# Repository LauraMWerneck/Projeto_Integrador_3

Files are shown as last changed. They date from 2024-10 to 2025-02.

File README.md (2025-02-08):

# 📦 Projeto Integrador 3 - Controle Automático de Caixa d'Água

## 🔍 Visão Geral

O **Projeto Integrador 3** tem como objetivo o desenvolvimento de um sistema inteligente para o controle automatizado de uma caixa d'água. O sistema foi projetado para monitorar e gerenciar o nível de água na caixa utilizando sensores e tecnologia de comunicação sem fio (Wi-Fi). A ESP32 é a placa responsável pela coleta dos dados e pela comunicação com o backend, enquanto o aplicativo web proporciona uma interface visual para o usuário.

### Funcionalidades Principais:
- **Monitoramento de Nível de Água:** O sensor ultrassônico HC-SR04 é utilizado para medir a distância da superfície da água, estimando seu nível e volume na caixa d'água.
- **Controle de Vazão:** O sensor de vazão YF-S201 é utilizado para monitorar a quantidade de água consumida e o fluxo de água na caixa.
- **Integração com a Internet:** A ESP32 utiliza Wi-Fi para enviar os dados coletados para um backend em Python, o qual armazena e processa as informações.
- **Exibição no Aplicativo:** O aplicativo web mostra os dados de vazão e nível de água em tempo real, permitindo que o usuário monitore a caixa d'água de forma intuitiva.
- **Controle da Válvula Solenóide:** O sistema inclui uma válvula solenóide controlada por um módulo relé, que permite desligar ou ligar o fluxo de água, dependendo dos dados de nível.

## 🚀 Como Funciona

### 1. **Sensores**
   O sistema conta com dois sensores principais:
   - **Sensor de Vazão (YF-S201):** Mede a quantidade de água que passa por um tubo, enviando pulsos à ESP32. A partir desses pulsos, a ESP32 calcula a vazão de água (litros por minuto) e o volume total consumido.
   - **Sensor Ultrassônico (HC-SR04):** Mede a distância entre o sensor e a superfície da água, permitindo calcular o nível de água na caixa. Isso é feito utilizando o tempo de retorno de um sinal ultrassônico.

### 2. **Placa e Circuito**
   A ESP32 é a central de processamento do sistema. Ela recebe os dados dos sensores, processa as informações e envia esses dados para o backend via Wi-Fi. O circuito inclui:
   - **Conversor de Tensão:** Para fornecer 5V aos sensores que exigem essa tensão de alimentação.
   - **Módulo Relé:** Controla a válvula solenóide para permitir o controle do fluxo de água.

### 3. **Backend**
   O backend é implementado em **Python** e recebe os dados enviados pela ESP32 através de requisições HTTP POST. Os dados são processados e armazenados, permitindo consultas e análises do comportamento do sistema.

### 4. **Aplicativo Web**
   O aplicativo web é a interface onde os dados são exibidos para o usuário. Ele mostra informações em tempo real sobre:
   - Nível de água na caixa.
   - Vazão de água e volume consumido.
   
   O backend envia as informações em formato JSON para o frontend (aplicativo web), permitindo a atualização automática e em tempo real da interface.

## 📂 Estrutura do Repositório

```
📦 Projeto_Integrador_3  
 ┣ 📂 Etapa 1               # Documentação do que foi desenvolvido na etapa 1  
 ┣ 📂 Etapa 2               # Documentação do que foi desenvolvido na etapa 2  
 ┣ 📂 Etapa 3               # Documentação do que foi desenvolvido na etapa 3  
 ┣ 📂 Etapa 4               # Documentação do que foi desenvolvido na etapa 4  
 ┣ 📂 Projeto Final         # Pasta com os códigos e esquemáticos finais  
     ┣ 📄 main.c            # Código da ESP32  
     ┣ 📄 app.py            # Código do servidor em Python  
     ┣ 📄 index.html        # Aplicativo para visualização dos dados  
     ┣ 📂 Placa             # Esquemáticos e layout da PCB  
 ┣ 📜 README.md             # Documentação principal  
 ┣ 📜 README_1.md           # Primeiro README.md feito com o resumo do objetivo do projeto  
```

## 💻 Requisitos

Para rodar o projeto, é necessário ter os seguintes componentes e softwares:

### Hardware:
- **ESP32 (ESP-WROOM-32)** – Microcontrolador responsável pelo processamento dos dados.
- **Sensor Ultrassônico HC-SR04** – Para medição do nível de água.
- **Sensor de Vazão YF-S201** – Para medir o fluxo de água.
- **Válvula Solenóide e Módulo Relé** – Para controlar o fluxo de água.
- **Conversor de Tensão** – Para alimentar os sensores.

### Software:
- **Python 3.x** – Para rodar o backend do servidor.
- **Bibliotecas ESP32** – Para programar a ESP32.
- **HTML/CSS/JavaScript** – Para o desenvolvimento da interface do aplicativo web.

## ⚙️ Como Rodar

### 1. **Configuração da ESP32:**
   - Baixe o código da ESP32 (main.c) e configure a placa utilizando o ESP-IDF do Visual Studio Code.
   - Conecte os sensores de vazão e ultrassônicos aos pinos apropriados na ESP32.
   - Configure a conexão Wi-Fi com as credenciais da sua rede.

### 2. **Configuração do Backend:**
   - Clone o repositório e instale as dependências necessárias para rodar o servidor em Python.
   - Execute o código Python (`app.py`) para iniciar o backend.
   - O backend estará escutando as requisições HTTP POST enviadas pela ESP32.

### 3. **Interface Web:**
   - Abra o arquivo `index.html` em um navegador para acessar a interface do aplicativo.
   - O frontend vai se conectar automaticamente ao backend para visualizar os dados em tempo real.

### 4. **Testes e Monitoramento:**
   - Teste o sistema monitorando os dados de vazão e nível de água, além de verificar o controle da válvula solenóide através da interface web.

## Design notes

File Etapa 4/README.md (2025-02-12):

# Resumo do que foi desenvolvido na etapa

## Comunicação WiFi da ESP (Sensores mandando dados para o aplicativo)

A primeira parte desenvolvida nessa etapa foi a implementação da comunicação entre a ESP32 e o backend do aplicativo, permitindo que a ESP enviasse os dados dos sensores de forma eficiente. Utilizando a conectividade Wi-Fi da ESP32, foi integrado o envio de dados coletados dos sensores (como vazão de água, volume total acumulado e distância medida por ultrassônico) para o backend, que é implementado em Python. O código de coleta de dados, previamente funcional, foi adaptado para incluir o envio dessas informações em formato JSON por meio de requisições HTTP POST ao servidor. Isso garante que os dados sejam transmitidos em tempo real, utilizando uma comunicação robusta e compatível com o backend.

Para testar essa funcionalidade, carregamos o novo código na ESP32 e executamos o código do backend em Python. Com as credenciais de Wi-Fi configuradas corretamente, os dados enviados pela ESP começaram a aparecer no terminal onde o backend estava rodando, conforme ilustrado na Figura 1. Além disso, para validar a estabilidade da comunicação Wi-Fi, conectamos a ESP a uma fonte de alimentação independente e observamos que ela continuou transmitindo os dados de forma consistente para o backend. Esse teste confirmou que a comunicação Wi-Fi estava funcionando corretamente e de maneira estável.

Figura 1: Backend recebendo dados no terminal via WiFi.
teste_wifi
Fonte: Autoria Própria.

Os códigos comentados utilizados para esse teste estão disponíveis [aqui](https://github.com/LauraMWerneck/Projeto_Integrador_3/tree/main/Etapa%204/Teste%20WiFi).

## Criação da Placa
Na análise do esquemático criado na Etapa 3, identificamos soluções mais simples e eficazes para atender aos requisitos do projeto. Adotamos uma fonte de 12V via conector P4, que alimenta tanto a solenóide através do relé quanto um conversor 7805 para fornecer 5V à ESP32 e aos sensores. Também substituímos o módulo de relé por um relé simples, tornando o circuito mais compacto e reduzindo custos sem comprometer a eficiência.

Durante os testes, identificamos instabilidades devido à ausência de capacitores de desacoplamento no 7805, especialmente ao acionar o relé. A adição desses capacitores estabilizou a alimentação. Além disso, o sensor de fluxo apresentou falhas com os 5,05V fornecidos pelo 7805, sendo corrigido com um diodo em série, reduzindo a tensão e melhorando seu desempenho.

Após os ajustes, o circuito revisado mostrou-se mais estável e eficiente. As melhorias foram implementadas diretamente no esquemático, conforme mostra a Figura 2 e no layout da PCB, como mostra a Figura 3, garantindo uma versão pronta para fabricação e montagem.

Figura 2: Novo esquemático do circuito.



Fonte: Autoria Própria.

Figura 3: Novo layout da placa.



Fonte: Autoria Própria.

Após a fabricação da placa, e a instalação dela no sistema físico de teste ela ficou como mostra a Figura 4.

Figura 4: Placa integrando todos os componentes.

Imagem do WhatsApp de 2025-02-10 à(s) 20 37 38_9340aac4

Fonte: Autoria Própria.

Para mais detalhes das modificações da placa, e para acessar o projeto do Kicad clique [aqui](https://github.com/LauraMWerneck/Projeto_Integrador_3/tree/main/Projeto%20Final/Placa)

## Sistema Físico de Teste
Como visto na Etapa 3, criamos um sistema físico de teste e, nesta última etapa, aprimoramos sua estrutura para acomodar a ESP e a nova placa de forma mais segura e com aparência de um produto final. Para isso, desenvolvemos um suporte impresso em 3D, fixado acima do balde principal, garantindo a estabilidade da ESP e dos sensores durante os testes. O projeto da impressão 3D está ilustrado na Figura 5.

Figura 5: Suporte 3D desenvolvido.

modelo_3D

Fonte: Autoria Própria.

Após a impressão da peça, e da integração da placa com os sensores o sistema físico de teste ficou como mostra a Figura 4, a Figura 6 e a Figura 7.

Figura 6: Suporte aberto no sistema físico de teste.

Imagem do WhatsApp de 2025-02-10 à(s) 21 38 06_a600479e

Fonte: Autoria Própria.

Figura 7: Suporte fechado no sistema físico de teste.

Imagem do WhatsApp de 2025-02-10 à(s) 21 37 33_552d8dbc

Fonte: Autoria Própria.

Para acessar o modelo 3D criado clique [aqui](https://www.tinkercad.com/things/hdSAljJmEcl-pi3?sharecode=l4aGRgi_aN5EzP9HnUlWbnjf8VeXGf09ikW7ILrOMxc)

## Criação das Funcionalidades do Aplicativo

O código do aplicativo app.py utiliza Flask para monitoramento do consumo de água e controle da caixa d'água. Ele recebe e processa dados de sensores, gerencia configurações e fornece informações para um painel em tempo real.

### **Principais Funcionalidades**
- **Recepção de Dados (/ESP_data):** Captura informações dos sensores, como distância, volume e vazão de água. Processa esses dados para calcular o consumo, estimar o tempo de disponibilidade da água e gerar alertas em caso de anomalias, como falta de água.
- **Cadastro de Configurações (/save_data):** Permite que o usuário registre informações como consumo do hidrômetro, custo da água e volume da caixa d’água. Os dados são armazenados para cálculos e análises futuras.
- **Logs em Tempo Real (/logs_stream):** Utiliza Server-Sent Events (SSE) para enviar atualizações contínuas ao frontend, garantindo que os dados exibidos na interface estejam sempre atualizados sem necessidade de recarregamento da página.
- **Leitura de Dados:** O sistema acessa um arquivo local para recuperar configurações e dados históricos do consumo, garantindo continuidade e rastreabilidade das informações.
- **Cálculos:**
  - **Custo por Litro de Água:** Obtido dividindo o custo total da água pelo consumo registrado.
  - **Consumo por Minuto e Hora:** O sistema armazena e exibe a taxa de consumo ao longo do tempo, permitindo uma análise detalhada do uso da água.
  - **Estimativa de Disponibilidade:** Com base na taxa de consumo e no volume atual da caixa d’água, o sistema prevê o tempo restante antes do esgotamento.
  - **Detecção de Falta de Água:** Se os sensores indicam um nível muito baixo, um alerta é gerado para notificar o usuário sobre o problema.

### **Interface Web**
A página HTML fornece uma interface interativa para o monitoramento e controle do consumo de água. Ela inclui:

- **Painel de Monitoramento:**
  - Exibe informações em tempo real sobre consumo, custo e volume disponível.
  - Apresenta alertas visuais sobre possíveis problemas, como baixo nível de água.
- **Gráficos Dinâmicos:**
  - Usa Chart.js para criar gráficos interativos que mostram o consumo de água ao longo do tempo.
  - O usuário pode alternar entre diferentes visualizações, como consumo por minuto, por hora ou por dia.
- **Logs de Alertas:**
  - Registra e exibe eventos importantes, como discrepâncias no consumo e notificações de falta de água.
  - Permite que o usuário acompanhe o histórico de alertas.
- **Formulário de Configuração:**
  - O usuário pode inserir e atualizar dados essenciais, como volume da caixa d’água, custo da água e consumo registrado.
  - Inclui campos para definir metas de consumo e monitorar os custos mensais.
- **Botões Interativos:**
  - Permitem alternar entre diferentes gráficos e logs.
  - Incluem funcionalidades para salvar e enviar novas configurações ao backend.

Os códigos do app.py e da página html podem ser acessados e ter sua documentação detalhada [aquqi](https://github.com/LauraMWerneck/Projeto_Integrador_3/tree/main/Projeto%20Final).

## Teste Final
Com todas as funcionalidades do aplicativo concluídas, a placa integrando os componentes e o sistema físico finalizado, além da comunicação Wi-Fi operando corretamente, chegou o momento de testar o projeto como um todo. O objetivo era garantir seu funcionamento conforme o esperado e verificar se os sensores estavam coletando os dados corretamente.

Assim, ligamos todo o sistema, conectamos os componentes necessários e, visualmente, o projeto com o sistema físico de teste ficou conforme ilustrado na Figura 8.

Figura 8: Protótipo Final.

Imagem do WhatsApp de 2025-02-10 à(s) 20 39 52_edbd3d94

Fonte: Autoria Própria.

Em seguida, inicializamos o sistema e abrimos o aplicativo. Nele, realizamos as configurações necessárias, e logo começou a receber os dados dos sensores e exibi-los para os usuários, conforme ilustrado na Figura 9.

Figura 9: Interface do Aplicativo.

Imagem do WhatsApp de 2025-02-11 à(s) 21 16 24_23b2c37d

Fonte: Autoria Própria.

# Conclusão do Projeto
O desenvolvimento deste projeto permitiu a integração eficiente de sensores de vazão e volume de água com a ESP32, garantindo a captação e transmissão de dados em tempo real para um aplicativo via Wi-Fi. A implementação bem-sucedida da comunicação entre os sensores e o backend assegurou um monitoramento contínuo e preciso dos níveis de água, proporcionando uma solução funcional para o controle de reservatórios.  

Ao longo das etapas, enfrentamos desafios técnicos como a escolha e calibração dos sensores, a revisão do circuito eletrônico e a estabilidade da comunicação Wi-Fi. A necessidade de ajustes no esquemático da placa e a reorganização dos componentes foram superadas, resultando em uma estrutura mais otimizada e confiável. Além disso, a implementação do backend em Python garantiu uma integração eficiente entre os sensores e o aplicativo, permitindo que os dados fossem processados e exibidos de maneira intuitiva para o usuário.  

O teste final comprovou o funcionamento adequado do sistema, validando a precisão das medições e a estabilidade da transmissão de dados. A interface do aplicativo foi aprimorada para facilitar o uso e a interpretação das informações coletadas. Apesar dos desafios enfrentados, o projeto demonstrou sua viabilidade e abriu caminhos para melhorias, como a otimização da precisão do sensor ultrassônico e a integração de novos recursos, como o controle automatizado da válvula solenoide.  

Com isso, o projeto atinge seu objetivo de oferecer uma solução acessível e eficiente para o monitoramento e controle de água em reservatórios, trazendo benefícios tanto para economia de recursos quanto para a gestão inteligente do consumo hídrico.

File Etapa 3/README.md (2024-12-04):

# Resumo do que foi desenvolvido na Etapa 3

## Testes Individuais dos Sensores

### Sensor de Vazão
Para testar o sensor de vazão (YF-S201), foi desenvolvido um código que recebe os pulsos gerados pelo sensor durante a passagem de água e calcula a vazão com base nesses pulsos e no fator de calibração específico do sensor. O código exibe os resultados do teste, mostrando a vazão em litros por minuto e litros por hora, além de informar o volume total de água que passou pelo sensor desde que o sistema foi iniciado. 

A explicação mais detalhada sobre o teste, juntamente com o código utilizado e sua documentação, está disponível neste [link](https://github.com/LauraMWerneck/Projeto_Integrador_3/blob/main/Etapa%203/Sensor%20de%20Vaz%C3%A3o/README.md).

### Sensor de Volume
Para validar o funcionamento do sensor ultrassônico HC-SR04 no cálculo de volumes de água, foi realizado um teste que avaliou sua precisão em medições de distância. O sistema integrou dados de distância e vazão, ajustando dinamicamente o ponto de referência do sensor conforme o nível de água. Durante o experimento, foram adicionados volumes graduais de água em um balde e comparados os níveis medidos pelo sensor com medições feitas por trena. Os resultados demonstraram que a relação entre o nível e o volume é não linear devido ao formato do recipiente, mas indicaram a viabilidade de criar funções para estimar automaticamente o volume em diferentes recipientes.

O código utilizado no teste, que configura o sensor, realiza medições contínuas e permite ajustes por comandos seriais, está documentado e disponível neste [link](https://github.com/LauraMWerneck/Projeto_Integrador_3/blob/main/Etapa%203/Sensor%20de%20Volume/README.md). O teste concluiu que o sensor ultrassônico é aplicável para medições dinâmicas de volume no projeto, com precisão suficiente para as demandas propostas.

## Integração de Todos os Sensores

Para integrar todos os sensores, começamos planejando o circuito com todos os componentes. Durante essa etapa e durante os testes individuais dos sensores, percebemos a necessidade de adicionar novos elementos, como o conversor de tensão e o módulo relé. Assim, foi elaborado o circuito que inclui não apenas os sensores, mas também a válvula solenóide. A Figura 1 a seguir apresenta o circuito resultante que montamos.

Figura 1: Circuito com os componentes e sensores.
circuito_componentes
Fonte: Autoria Própria.

Este circuito é composto pelo módulo ESP32 (ESP Wroom 32), o sensor de vazão YF-S201, o sensor ultrassônico HC-SR04, uma válvula solenóide, um módulo relé de 5V e um conversor de tensão. A ESP32 alimenta o conversor de tensão, que, por sua vez, fornece energia para os sensores e o módulo relé. A ESP32 é conectada aos sensores por meio de suas saídas de dados. A válvula solenóide e o módulo relé são alimentados por uma fonte de 12V.

É importante ressaltar que para esse primeiro teste de integração de todos os sensores, foi montado um circuito com os componentes principais, sem a inclusão do módulo relé e da válvula solenóide.

### Testes Experimentais

Para a realização dos testes com a integração de todos os sensores, foi desenvolvido um código que combinou tanto a parte do sensor de vazão quanto a do sensor de volume. Entretanto, para os testes dos sensores, foi montado um circuito com os componentes principais, mas sem a inclusão do módulo relé e da válvula solenóide.. A documentação detalhada desse código pode ser acessada através deste [link](https://github.com/LauraMWerneck/Projeto_Integrador_3/blob/main/Etapa%203/Integra%C3%A7%C3%A3o%20dos%20Sensores/README.md), e o código completo está disponível neste outro [link](https://github.com/LauraMWerneck/Projeto_Integrador_3/blob/main/Etapa%203/Integra%C3%A7%C3%A3o%20dos%20Sensores/integracao_sensores.c).

Inicialmente, o circuito e os sensores foram testados sem água, apenas com o circuito montado. No caso do sensor de volume (ultrassônico), foi realizada a medição de distância ao afastar e aproximar a mão da entrada do sensor. Para testar o sensor de vazão, foi simulado o fluxo de água ao assoprar na entrada do sensor, fazendo com que a hélice girasse como se a água estivesse passando. Um vídeo desse teste inicial pode ser visualizado abaixo.

Vídeo 1: Primeiro teste com todos os sensores.

https://github.com/user-attachments/assets/cf840823-a034-4f19-821a-5b99ec565559

Fonte: Autoria Própria.

Foi realizado um segundo teste, desta vez utilizando água. Esse teste considerou o sistema físico que montamos, composto por dois baldes, uma bomba de água e tubulações. O funcionamento do sistema é o seguinte: o balde inferior, cheio de água, alimenta a bomba, que utiliza uma mangueira conectada ao sensor para bombear a água. Após passar pelo sensor, a água é conduzida por outra mangueira e despejada no balde superior. O sensor de volume (ultrassônico) foi posicionado acima do balde superior para medir a distância entre o sensor e a superfície da água.

As Figura 2, 3 e 4 mostram como ficou o sistema físico montado, os resultados obtidos no teste forma os mesmos do testado sem água, somente o sensor ultrassônico que notamos que ele não calcula tão corretamente a distância da superfície da água, mas isso já está sendo estudado e resolvido.

Figura 2: Sistema físico de teste.

sistema_fisico_3

Fonte: Autoria Própria.

Figura 3: Sistema físico visto por cima.

sistema_fisico_2

Fonte: Autoria Própria.

Figura 4: Sistema físico vista lateral.

sistema_fisico_1

Fonte: Autoria Própria.

### Criação do Circuito Completo

Para a criação do circuito completo, consideramos os principais componentes do nosso projeto: os sensores de vazão (YF-S201) e ultrassônico (HC-SR04), além da ESP32 (ESP Wroom 32). Durante o processo, identificamos a necessidade de utilizar um conversor de tensão de 3,3V para 5V, pois o sensor ultrassônico só funcionava corretamente com essa alimentação. Além disso, o sensor de vazão apresentou melhor calibragem e resultados mais precisos quando operando com 5V. Para atender a essa demanda, utilizamos um Módulo Regulador de Tensão Ajustável MT3608 Step Up - 2,5V a 28V, aproveitando um material que já tinhamos disponível e garantindo que fosse adequado às nossas necessidades.

Adicionalmente, pensando na próxima etapa do projeto, incluímos ao circuito uma válvula solenoide. Essa válvula será responsável por controlar o fluxo de água, permitindo ou bloqueando sua passagem conforme necessário para regular o volume no reservatório. Para gerenciar a válvula, percebemos a necessidade de incluir um módulo relé, o qual também já possuíamos. A utilização desse componente irá nos permitir integrar facilmente o controle da válvula ao circuito, otimizando os recursos disponíveis.

Dessa forma, o circuito foi montado ficou como mostrado na Figura 1 e o esquemático desse circuito como mostra a Figura 2.

Figura 5: Esquemático do projeto.

esquematico

Fonte: Autoria própria.

Neste esquemático, utilizamos bibliotecas prontas para o módulo ESP32 e para o sensor ultrassônico. Entretanto, foi necessário criar os símbolos representativos para os demais componentes do circuito. Assim, desenvolvemos símbolos personalizados para representar os componentes adicionais. 

Para a elaboração da placa com os footprints, foi necessário modificar o esquemático original, uma vez que alguns componentes já possuíam conexões pré-estabelecidas ou não estariam conectados diretamente à placa. Como resultado, o esquemático final da placa ficou conforme ilustrado na Figura 3.

Figura 6: Esquemático da placa.

esquematico2

Fonte: Autoria Própria.

Para os *footprints*, utilizamos modelos já existentes para alguns itens, como o sensor de vazão (YF-S201). Em outros casos, foi necessário criar nossos próprios *footprints*, como para o regulador de tensão. O resultado final do circuito da placa que será fabricada, é apresentado na Figura 4.

Figura 7: *Layout* da PCB.

circuito_placa

Fonte: Autoria Própria.

## Desenvolvimento do Aplicativo

No aplicativo, a comunicação entre o backend e o frontend foi implementada por meio de uma API, permitindo que o usuário insira os valores necessários, que são salvos e utilizados para cálculos no backend. A próxima etapa do desenvolvimento incluirá a integração para o recebimento dos dados provenientes do microcontrolador, a transmissão dos resultados do backend para o frontend e a criação de uma interface amigável para o usuário.

Confira mais detalhes no repositório: [Projeto Integrador 3 - Aplicativo](https://github.com/LauraMWerneck/Projeto_Integrador_3/tree/main/Etapa%203/Aplicativo)

## Identificação dos Problemas

Durante o desenvolvimento do projeto diversos desafios foram enfrentados e documentados para que pudessem ser adequadamente analisados e resolvidos. Esses problemas estão relacionados tanto ao hardware quanto à implementação e integração dos componentes eletrônicos. A seguir, são detalhados os problemas identificados até o momento:

#### 1. Utilização de Pinos de Strapping na ESP32 WROOM  
Durante a montagem inicial do circuito, foram utilizados os pinos 2 e 5 da ESP32 WROOM, que são pinos críticos para o processo de "strapping". Isso gerou dificuldades ao tentar gravar o código na ESP32, já que o pino 2 é diretamente relacionado ao processo de boot. Como solução temporária, foi adotada a prática de pressionar manualmente o botão de boot durante o envio do código para a placa. No entanto, essa abordagem é pouco prática e pode gerar problemas futuros caso a necessidade de regravação do código seja frequente ou automatizada. Esse problema foi identificado e os pinos serão remanejados para evitar conflitos com as funções de strapping.

#### 2. Má utilização do Visual Studio Code
Durante o desenvolvimento do projeto, enfrentamos dificuldades ao abrir o monitor serial no Visual Studio Code, usado para programar e gravar o código na ESP32. O problema ocorreu devido a erros na organização dos arquivos do projeto e na configuração do sistema de build baseado em CMake. Criamos arquivos de maneira incorreta dentro do projeto, e o arquivo `CMakeLists.txt` não foi ajustado para identificar corretamente o arquivo principal com a função `main`. Isso gerou inconsistências durante a compilação, fazendo com que o código fosse gravado de forma incorreta na ESP32 e impedindo que o monitor serial exibisse as mensagens de saída esperadas. Para resolver, reorganizamos os arquivos respeitando a estrutura padrão do ESP-IDF. Após essa mudança, o sistema passou a compilar corretamente, e o monitor serial voltou a funcionar.

#### 3. Baixa Precisão do Sensor Ultrassônico  
O sensor ultrassônico instalado para medir o volume de água na caixa apresentou limitações de precisão nas leituras. Isso pode comprometer a confiabilidade do sistema de controle, especialmente em situações que demandam maior exatidão nos dados. Já está em andamento a investigação de possíveis melhorias no uso do sensor, como ajustes na sua posição ou alterações no código de processamento dos dados, além da análise de alternativas de sensores que possam substituir o atual.

#### 4. Integração do Sistema e Comunicação com o Aplicativo  
Embora ainda não tenha gerado problemas práticos, a integração dos dados coletados pelos sensores e sua transmissão para o aplicativo via HTML podem ser pontos de atenção. A confiabilidade na comunicação entre a ESP32 e o aplicativo será essencial para o funcionamento do sistema, especialmente em termos de velocidade e consistência na transmissão dos dados.

#### 5. Organização dos Sensores e da Placa de Controle
Outro ponto inportante para termos atenção para a próxima etapa está relacionado à organização física dos sensores, da válvula solenóide e da placa de controle. Como o projeto inclui uma placa principal com os componentes eletrônicos essenciais e conexões externas para os sensores e a válvula, é necessário planejar cuidadosamente a disposição dos cabos, a localização da placa e as medidas de proteção física para garantir a funcionalidade e a durabilidade do sistema.

Esse desafio envolve evitar o emaranhamento dos fios, que pode dificultar a manutenção e gerar interferências elétricas entre os componentes, além de pensar em uma forma de fixar a placa em um local seguro. Também é necessário garantir que a placa e as conexões estejam protegidas contra umidade, respingos de água e outras condições ambientais adversas, utilizando uma caixa ou invólucro adequado. Este problema ainda está em análise para definir a melhor solução, considerando tanto a praticidade quanto os custos envolvidos na implementação de uma organização eficiente e segura.

## Estudo da Viabilidade de Monitorar Vazamentos
O estudo de viabilidade para implementar o monitoramento de vazamentos no projeto de controle da caixa d’água concluiu que a funcionalidade não é viável devido a limitações técnicas e financeiras. O sensor de vazão existente não permite detectar vazamentos na tubulação, e a instalação de sensores adicionais aumentaria os custos e a complexidade. Métodos alternativos, como o uso de dados comparativos com o sensor ultrassônico, são imprecisos e sujeitos a falsos alarmes. Além disso, o ambiente operacional, com baixa pressão e tubulações conectadas em diferentes pontos, dificulta a confiabilidade do sistema.

Dado o alto custo de sensores especializados e a manutenção necessária para evitar falhas, optou-se por não incluir essa funcionalidade no projeto. O foco será para melhorar o controle de enchimento da caixa e a apresentação dos dados no aplicativo, mantendo a solução acessível, eficiente e funcional.

Mais detalhes do que foi levantado nessa pesquisa podem ser acessados nesse [link](https://github.com/LauraMWerneck/Projeto_Integrador_3/tree/main/Etapa%203/Estudo%20da%20Viabilidade%20de%20Monitorar%20Vazamentos)

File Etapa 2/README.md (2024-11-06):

# Resumo do que foi desenvolvido na Etapa 2

## Determinação das Fórmulas do Aplicativo

### Dados Retornados pelo Microcontrolador
O microcontrolador envia dados para o backend, usados para calcular o custo da água na região, com base nas informações da conta de água inseridas pelo usuário.

### Cálculos no Aplicativo

1. **Consumo em Reais**: Calculado considerando a hora e data.
2. **Água Disponível na Caixa d’Água**: Cálculo baseado na quantidade de água.
3. **Consumo Real**: Diferença entre o valor calculado e o hidrômetro.
4. **Tempo de Água Disponível**: Calculado com base no consumo dos últimos 3 dias.
5. **Expectativa de Consumo**: Estimativa para o próximo mês, após o primeiro mês de uso.
6. **Gasto no Próximo Mês**: Usuário define o limite, disponível após o primeiro mês.

### Funcionalidades Sem Fórmulas
- **Limitar Aviso**: Notifica sobre excesso de gasto.
- **Próxima Manutenção**: Notifica a data da próxima manutenção.

## Especificações do Sensor de Vazão YF-S201

### Descrição
O YF-S201 é um sensor de vazão de água utilizado em projetos eletrônicos e industriais para medir o fluxo de líquidos. Ele é simples, de baixo custo e funciona detectando pulsos gerados por um rotor acionado pelo fluxo de água.

### Especificações Técnicas
- **Faixa de Medição**: 1 a 30 L/min
- **Tensão de Operação**: 5 a 18V
- **Corrente Máxima**: 15 mA
- **Temperatura**: -25°C a 80°C
- **Pressão Máxima**: 1,75 MPa
- **Conexão**: Rosca G1/2" (uso doméstico e industrial)

### Funcionamento
A água aciona um rotor que gera pulsos detectados por um sensor de efeito Hall. Cada 450 pulsos representam 1 litro de água. A vazão pode ser calculada com a fórmula:

Fluxo (L/min) = Frequência de Pulsos (Hz) / 7,5

## Desenvolvimento de Firmware para Comunicação com o Sensor YF-S201

### Objetivo
O objetivo foi testar a comunicação entre o sensor YF-S201 e o microcontrolador ESP32 para medir a vazão de água. O firmware foi desenvolvido para ler e processar os pulsos gerados pelo sensor e calcular a vazão em litros por minuto.

### Funcionamento
- O sensor gera pulsos que são capturados pelo pino GPIO da ESP32.
- Cada pulso corresponde a uma quantidade específica de água, definida pela constante **PULSOS_POR_LITRO (450 pulsos por litro)**.
- A vazão é calculada a partir da frequência dos pulsos.

### Código de Teste
O código configura o pino GPIO4 da ESP32, instala uma interrupção para contar os pulsos, e calcula a vazão com base nos pulsos detectados.

### Resultados
O sistema exibe a vazão em tempo real no monitor serial da ESP32. Inicialmente, o teste foi feito utilizando vento para girar o rotor do sensor.

## Especificações do Sensor Ultrassônico HC-SR04

### Descrição
O HC-SR04 é um sensor ultrassônico usado para medir distâncias e é amplamente aplicado em projetos de controle de nível de líquidos. Ele emite ondas ultrassônicas que retornam após atingirem a superfície do líquido, permitindo calcular a distância.

### Especificações Técnicas
- **Distância de Medição**: 2 cm a 4 m
- **Tensão de Operação**: 5V
- **Precisão**: Aproximadamente 3 mm
- **Frequência**: 40 kHz
- **Função**: Ideal para monitoramento e controle de nível de água em reservatórios e caixas d'água.

# Desenvolvimento de Firmware para Comunicação com o Sensor Ultrassônico HC-SR04

Nesta etapa, foi implementada a medição de distância utilizando o sensor ultrassônico HC-SR04 com o microcontrolador ESP32, através do framework ESP-IDF no Visual Studio Code. O objetivo era medir a distância até a superfície da água, utilizando o sensor para controle de nível de líquidos.

### Configuração e Conexões
- O sensor HC-SR04 foi conectado ao ESP32, com o pino **TRIG** no GPIO4 e o pino **ECHO** no GPIO2.
- Como o sensor exige 5V para alimentação, foi utilizada uma fonte externa de 5V, com o GND conectado ao GND do ESP32.

### Estrutura do Código
- A função **`init_ultrasonic_sensor`** configura os pinos TRIG e ECHO.
- **`measure_distance`** envia um pulso no pino TRIG e calcula o tempo de resposta no pino ECHO, utilizando esse tempo para calcular a distância.
- **`ultrasonic_task`** é responsável por realizar a leitura contínua da distância em intervalos de 1 segundo, com um sistema de watchdog para evitar travamentos.
- A função **`app_main`** inicializa a tarefa de leitura do sensor.

Com a implementação concluída, o sistema realiza a medição da distância e exibe o resultado em tempo real no monitor serial.

## Descrição do Sistema Físico de Teste

O sistema de teste será composto por três componentes principais: sensor de vazão YF-S201, válvula solenoide e sensor ultrassônico. A ESP32 será responsável por controlar os sensores e acionar a válvula.

### Estrutura do Sistema:
- **Mangueira transparente** conectada ao registro de água.
- **Sensor de vazão** YF-S201 e **válvula solenoide** acoplados a uma peça 3D para controle do fluxo de água.
- **Balde** representando a caixa d'água, com válvula de saída para simulação de vazão.
- **Sensor ultrassônico** montado na tampa do balde para medir o nível de água.

O sistema conta com um segundo balde para escoar a água durante os testes. Para otimizar a conexão entre a válvula e o sensor de vazão, foi projetada uma peça personalizada em 3D para corrigir a discrepância nos diâmetros internos, prevenindo problemas como cavitação.

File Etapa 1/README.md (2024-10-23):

# Resumo do que foi desenvolvido na Etapa 1

Nesta etapa do projeto, foi realizada uma pesquisa sobre os componentes necessários e como desenvolver um aplicativo 
para monitorar e controlar um sistema hidráulico utilizando um microcontrolador. A pesquisa abordou tanto os aspectos de hardware 
quanto de software, além da escolha de novos componentes como válvulas solenoides e relés que serão necessários para o funcionamento 
completo do sistema.

## Microcontrolador Selecionado

O microcontrolador escolhido foi o ESP32 WROOM, devido ao seu custo-benefício e sua capacidade de atender aos requisitos do projeto, 
como conectividade Wi-Fi e compatibilidade com diversos sensores. Além disso, o ESP32 oferece uma solução mais barata e eficiente em 
comparação com a Raspberry Pi Pico W, que também foi pesquisada como opção, sem comprometer o desempenho necessário para o projeto.

## Desenvolvimento do Aplicativo

O desenvolvimento do aplicativo foi pensado para integrar um microcontrolador ESP com um backend em Python e um frontend em HTML.
A escolha por Python no backend se deu por sua facilidade de uso e sua vasta biblioteca de suporte para comunicação com microcontroladores, especialmente no recebimento e processamento de dados em tempo real.

O frontend em HTML já está parcialmente desenvolvido e oferece uma interface amigável para que os usuários possam monitorar e controlar o 
sistema. A integração completa com o backend será realizada após os testes com o ESP32, assegurando que a comunicação e o desempenho do 
hardware sejam validados antes de avançar com a lógica do backend.

## Sensor de Vazão - YF-S201

O sensor de vazão YF-S201 foi escolhido após uma análise de diversos modelos. Este sensor é capaz de medir o fluxo de água entre
1 a 30 litros por minuto e é compatível com o ESP32, operando a 5V. A integração será realizada através de leitura de pulsos digitais
gerados pelo sensor, que serão convertidos em leituras de vazão pelo microcontrolador.

**Especificações do YF-S201:**
- Faixa de Medição: 1 a 30 L/min
- Tensão de Operação: 5 a 18V DC
- Compatibilidade: ESP32 (3.3V nos pinos digitais)

**Justificativa da Escolha:**
- **Compatibilidade com ESP32:** Fácil integração com leitura de pulsos digitais.
- **Faixa de Vazão:** Adequada para sistemas domésticos de abastecimento.
- **Custo Benefício:** Preço acessível e disponibilidade no laboratório.

## Sensor de Nível de Água - HC-SR04

Para a medição de nível de água, foi selecionado o sensor ultrassônico HC-SR04, que oferece uma medição linear com alta precisão,
embora não seja à prova d'água. Sua faixa de medição vai de 2 cm a 4 metros, sendo ideal para monitoramento de níveis em caixas d'água
de pequeno e médio porte.

**Especificações do HC-SR04:**
- Faixa de Medição: 2 cm a 4 metros
- Precisão: 3 mm

### Simulação Realizada

Foi realizada uma simulação do sensor ultrassônico HC-SR04 utilizando a plataforma TinkerCAD. A simulação permitiu verificar o funcionamento básico do sensor, medindo a distância até o objeto mais próximo e exibindo os resultados em um monitor serial. O código utilizado simulou o envio e recebimento de pulsos ultrassônicos, calculando a distância com base no tempo de retorno. Essa simulação forneceu uma visão inicial do comportamento do sensor no sistema, o que facilita os ajustes necessários para a implementação no projeto real.

### Novos Componentes Adicionados

Durante as pesquisas, identificamos a necessidade de novos componentes para o sistema:
- **Válvula Solenoide:** Para controle automatizado do fluxo de água.
- **Relés:** Para ativar ou desativar a válvula e outros dispositivos elétricos do sistema.

Esses componentes serão integrados ao projeto para garantir o controle preciso do sistema hidráulico.

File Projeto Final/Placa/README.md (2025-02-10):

# Desenvolvimento da PCI

## Problemas encontrados na etapa anterior

Analisando a placa anterior, identificamos soluções mais simples e eficazes para atender aos requisitos do projeto. A alimentação foi repensada, adotando uma fonte de 12V conectada via P4, capaz de alimentar tanto a solenóide de 12V através do relé quanto um conversor 7805, que fornece 5V para a ESP32 e os sensores, garantindo seu funcionamento adequado. Além disso, substituímos o módulo de relé por um relé simples, resultando em uma construção mais compacta, reduzindo a complexidade e os custos sem comprometer a eficiência do sistema.

Figura 1: Esquemático do projeto.



## Fase de Testes

Durante a fase de testes, identificamos alguns problemas relacionados à estabilidade do circuito. Inicialmente, o 7805 foi utilizado sem capacitores de desacoplamento, o que resultou em instabilidades no funcionamento do sistema, especialmente ao acionar o relé com a válvula solenóide conectada. Para resolver esse problema, adicionamos capacitores de desacoplamento ao circuito, garantindo uma alimentação mais estável.

Figura 2: Capacitores de desacoplamento.



Outro problema identificado foi a instabilidade do sensor de fluxo quando operando com os 5,05V fornecidos pelo 7805. Para corrigir essa questão, inserimos um diodo em série, reduzindo a tensão de alimentação do sensor para aproximadamente 4,7V, o que melhorou significativamente seu desempenho.

Figura 3: Diodo redutor de tensão.



## Layout e 3D

Com as correções apresentadas anteriormente, o circuito revisado apresentou um funcionamento mais estável e eficiente. As alterações foram implementadas diretamente no esquemático e no layout da PCB, garantindo que a nova versão esteja adequada para fabricação e montagem.

Figura 4: Layout PCB.



Figura 5: Visualização 3D.



## Lista de Componentes

1x Conector p4

1x Barra pino femea

1x Barra pino macho

2x diodo 1N4007

1x Conector KRE 2 pinos

1x Capacitor 0.33uF

1x Capacitor 0.1uF

1x 7805

1x Relé 5V SRD-05VDC-SL-C

1x Dissipador TO-220

## Placa montada final

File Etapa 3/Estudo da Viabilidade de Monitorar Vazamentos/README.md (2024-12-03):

# Estudo de Viabilidade do Monitoramento de Vazamentos

Como parte do desenvolvimento do projeto de controle da caixa de água, foi realizado um estudo preliminar para avaliar a 
viabilidade técnica e operacional de incluir um sistema de monitoramento de vazamentos. A proposta consistia em detectar 
vazamentos ao longo da tubulação ou na própria caixa d’água, utilizando os sensores já integrados ao projeto ou componentes 
adicionais. No entanto, após uma análise detalhada, concluiu-se que a implementação dessa funcionalidade não seria viável, pelos 
seguintes motivos:

### 1. Limitações dos Sensores Disponíveis
O sensor de vazão YFS201, utilizado no projeto, mede exclusivamente a quantidade de água que passa pelo fluxo na tubulação principal. 
Para detectar vazamentos, seria necessário instalar sensores adicionais ao longo de toda a tubulação para identificar discrepâncias 
localizadas. Isso aumentaria significativamente a complexidade e o custo do sistema.

### 2. Baixa Precisão no Monitoramento Indireto  
Uma alternativa seria detectar vazamentos de forma indireta, comparando os dados do sensor de vazão com o volume de água registrado 
pelo sensor ultrassônico. Contudo, essa abordagem é limitada pela precisão do sensor ultrassônico, que já apresentou dificuldades para 
medir o volume com exatidão. Pequenas variações ou erros de leitura poderiam ser interpretados como vazamentos falsos.

### 3. Custo Elevado para Implementação  
A instalação de sensores adicionais específicos para monitoramento de vazamentos, como sensores de pressão ou sensores acústicos, 
exigiria um investimento significativo. Isso iria contra o objetivo de manter o projeto acessível e de baixo custo, um dos critérios 
centrais para sua viabilidade.

### 4. Condições Operacionais do Ambiente  
A detecção de vazamentos é especialmente desafiadora em sistemas de abastecimento de água com baixa pressão, tubulações extensas 
ou ramificadas. No ambiente estudado, essas condições tornariam ainda mais complexa a implementação de um sistema confiável de detecção.

### 5. Manutenção e Confiabilidade 
Sensores de vazamento frequentemente requerem manutenção para evitar alarmes falsos causados por fatores externos, como vibrações 
ou variações de pressão. Isso aumentaria a necessidade de intervenções regulares, dificultando a operação prática do sistema.

## Conclusão do Estudo 

Com base nos fatores analisados, conclui-se que a implementação de um sistema de monitoramento de vazamentos não é viável 
dentro do escopo e das limitações técnicas, financeiras e operacionais do projeto. Por essa razão, optou-se por não incluir 
essa funcionalidade no sistema, concentrando os esforços na melhoria dos aspectos centrais do projeto, como o controle de enchimento 
da caixa d’água e a apresentação dos dados no aplicativo. Essa decisão permite manter o foco na entrega de uma solução robusta e 
funcional para o controle eficiente de água.

### Referências

ASSIS JR., Luis Barbosa de; SILVA, Fabrício Lopes e; HENRIQUES, Felipe da Rocha; GUERRA, Raphael Pereira de Oliveira; CARVALHO, Cristiano de Souza de; BRANDÃO, Diego Nunes. *Construção e validação de um sistema IoT de baixo custo para detecção de vazamento de água em residências*. Disponível em: https://periodicos.univali.br/index.php/acotb/article/view/18806/10796. Acesso em: 28 nov. 2024.

GLDS. *Detector de vazamento de água DIY: Faça seu próprio dispositivo*. Disponível em: https://glds.com.br/detector-de-vazamento-de-agua-diy-faca-seu-proprio-dispositivo/. Acesso em: 28 nov. 2024.

MORAIS, Igor Almeida de. *Detecção de vazamento de fluidos em tubulações: métodos externos, internos e aplicação de aprendizado de máquina*. Universidade Federal de Uberlândia, Uberlândia, 2023. Disponível em: https://repositorio.ufu.br/bitstream/123456789/36975/1/Detec%C3%A7%C3%A3oVazamentoFluidos.pdf. Acesso em: 28 nov. 2024.

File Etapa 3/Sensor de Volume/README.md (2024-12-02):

# Teste Individual do Sensor de Volume Ultrassônico

Este teste avaliou o funcionamento de um sistema baseado no sensor ultrassônico **HC-SR04** para medições de distância. O objetivo foi validar a precisão do sensor e sua aplicação em cálculos de volume de água, integrando dados de distância e vazão.

## Documentação do Código

O código pode ser acessado através deste [link](https://github.com/StanisLK/Projeto_Integrador_3/blob/main/Etapa%203/Sensor%20de%20Volume/Sensor%20volume.c).

### Dependências e Bibliotecas Utilizadas

- **Ultrassônico:**
  - `<stdio.h>`: Entrada e saída.
  - `<stdint.h>`: Tipos de dados.
  - `<stdbool.h>`: Controle booleano.
  - `freertos/FreeRTOS.h`: Multitarefa.
  - `driver/gpio.h`: Manipulação de pinos GPIO.
  - `esp_timer.h`: Temporização.
  - `esp_task_wdt.h`: Watchdog Timer.

### Configurações do Sensor

- **Sensor Ultrassônico:**
  - `TRIG_PIN`: GPIO conectado ao pino TRIG.
  - `ECHO_PIN`: GPIO conectado ao pino ECHO.
  - `TIMEOUT_US`: Tempo limite para medição ultrassônica (25 ms).

### Funções Principais

#### Sensor Ultrassônico
1. **`init_ultrasonic_sensor`**: Configura os pinos TRIG e ECHO.
2. **`measure_distance`**: Mede a distância com base no tempo do sinal de eco.
3. **`ultrasonic_task`**: Executa medições contínuas e ajusta o ponto de referência quando necessário.

#### Comunicação UART
1. **`uart_task`**: Monitora a entrada serial para comandos, como ajuste do ponto de referência do sensor ultrassônico.

#### Fluxo Geral
1. Configuração e inicialização do sensor.
2. Execução simultânea das medições de distância e vazão.
3. Comunicação serial para ajustes e monitoramento.

### Saída
Durante a execução, o programa exibe no terminal:
- Vazão em Litros por Minuto (L/min).
- Distância em centímetros (cm).

## Resultados Obtidos com o Teste

### Etapas do Teste
1. O sensor foi configurado para ajustar dinamicamente a base de medição, utilizando o nível mínimo de água como referência.
2. Adicionou-se 1 litro de água em um balde, verificando a medição do nível de água com o sensor e comparando-a com uma trena.

### Dados Coletados
Após adicionar de 0 a 5 litros de água no balde, foram registrados os seguintes valores de nível medido (em cm):

| Volume (L) | Nível Medido (cm) |
|---|---|
| 0 | 0.00 |
| 1 | 3.96 |
| 2 | 7.22 |
| 3 | 10.88 |
| 4 | 13.92 |
| 5 | 16.47 |

### Curva de Nível x Volume

A curva gerada demonstra que a relação entre o nível medido e o volume não é linear, devido ao formato do recipiente utilizado, conforme imagem a seguir. O gráfico e sua análise indicam a possibilidade de criar uma função de mapeamento para estimar automaticamente o volume de água em diferentes tipos de recipientes, sem necessidade de especificação manual de dimensões.
Curva de Volume x Nível

  Configuração do Sistema

### Imagens do Teste

  Medição com Trena

  Sensor em Operação

  
 
  

### Conclusão
Este teste reforça a aplicabilidade do sensor ultrassônico na medição dinâmica de volumes de água, sendo uma abordagem viável e suficientemente precisa para a aplicação neste projeto.

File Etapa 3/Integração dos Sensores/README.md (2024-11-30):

# Integração dos Sensores

Nesta etapa, foi realizada a integração de todos os sensores, incluindo o sensor de vazão (YF-S201) e o sensor de volume (HC-SR04).
Para isso, foi desenvolvido um código que combina o controle de vazão, previamente testado, com o cálculo de distância do sensor de volume.

## Documentação do Código

O código pode ser acessado através deste [link](https://github.com/LauraMWerneck/Projeto_Integrador_3/blob/main/Etapa%203/Integra%C3%A7%C3%A3o%20dos%20Sensores/integracao_sensores.c).

### Dependências/Bibliotecas Incluídas:
- `<stdio.h>`: Para funções de entrada e saída, como `printf`.
- `<stdint.h>`: Para tipos de dados de largura fixa, como `uint32_t`.
- `<stdbool.h>`: Para uso do tipo `bool`.
- `freertos/FreeRTOS.h` e `freertos/task.h`: Para utilização do FreeRTOS, permitindo multitarefa.
- `driver/gpio.h`: Para manipulação dos pinos GPIO do ESP32.
- `esp_timer.h`: Para operações relacionadas a temporização.
- `esp_task_wdt.h`: Para o watchdog timer, garantindo que tarefas longas sejam monitoradas.

### Constantes
- `ULTRASONIC_TRIG_PIN` e `ULTRASONIC_ECHO_PIN`: Definem os pinos GPIO usados pelo sensor ultrassônico.
- `YFS201_PIN`: Pino GPIO usado pelo sensor de vazão YF-S201.
- `TIMEOUT_US`: Define o tempo máximo para medir distância pelo sensor ultrassônico.
- `PULSOS_POR_LITRO`: Especifica o número de pulsos gerados pelo sensor YF-S201 por litro de água.

### Variáveis Globais
- `contador_pulsos`: Variável volátil que registra o número de pulsos detectados pelo sensor de vazão.
- `ultrasonicTaskHandle` e `flowTaskHandle`: Handles para gerenciar as tarefas do FreeRTOS.

### Funções

`contar_pulsos(void* arg)`: Função de interrupção associada ao sensor YF-S201. Ela incrementa o contador de pulsos a cada sinal detectado.

`init_ultrasonic_sensor()`: Configura os pinos GPIO para o sensor ultrassônico: TRIG como saída e ECHO como entrada.

`measure_distance()`: Realiza a medição da distância usando o sensor ultrassônico. Isso é feito gerando um pulso de 10 µs 
no pino TRIG. Após isso espera o início do pulso de retorno no pino ECHO. Com isso, mede o tempo de subida e descida do pulso
e calcula a distância. A função retorna a distância medida ou -1 em caso de timeout.
  
`ultrasonic_task(void *pvParameters)`: Responsável por medir e exibir a distância continuamente. Ela inicializa o sensor ultrassônico, 
mede a distância a cada 1 segundo e exibe a distância no terminal.

`setup_yfs201_gpio()`: Configura o GPIO do sensor de vazão YF-S201: define o pino como entrada e configura a interrupção para 
detectar pulsos.
  
`flow_task(void *pvParameters)`: Responsável por medir a vazão de água e o volume acumulado. Configura o GPIO do sensor de vazão e 
calcula a vazão e o volume em intervalos de 1 segundo. Após o cálculo exibe os resultados no terminal.

`supervisor_task(void *pvParameters)`: Gerencia a criação e execução das tarefas dos sensores. Ela cria as tarefas `ultrasonic_task` 
e `flow_task`. Além disso exibe mensagens de supervisão a cada 2 segundos.

`app_main()`: Função principal executada ao iniciar o microcontrolador. Ela cria a tarefa de supervisão com prioridade máxima.

### Fluxo do Programa
1. **Inicialização**:
   - Configuração dos pinos GPIO para os sensores.
   - Registro da função de interrupção para o sensor de vazão.
2. **Execução das Tarefas**:
   - **`ultrasonic_task`**: Mede e exibe a distância usando o sensor ultrassônico.
   - **`flow_task`**: Calcula e exibe a vazão e o volume total de água.
   - **`supervisor_task`**: Supervisiona a execução das outras tarefas.
3. **Resultados**:
   - Distância medida pelo sensor ultrassônico.
   - Vazão em litros por minuto.
   - Volume acumulado em litros.

### Saída
Durante a execução, o programa exibe no terminal:
- **Distância (cm)**: Medida pelo sensor ultrassônico.
- **Vazão (L/min)**: Taxa de fluxo de água calculada pelo sensor de vazão.
- **Volume Total (L)**: Volume acumulado de água.

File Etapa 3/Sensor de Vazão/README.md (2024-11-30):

# Teste Individual do Sensor de Vazão

Nesta etapa, foi realizado um teste individual do sensor de vazão (YF-S201) para validar seu funcionamento e verificar se o fator de calibração estava correto, garantindo que ele apresentasse um valor real do volume de água que passou pelo sensor. Para isso, foi desenvolvido um código capaz de receber os pulsos gerados pelo sensor durante a passagem de água e calcular a vazão com base nesses pulsos e no fator de calibração correspondente. O código apresenta os resultados do teste, exibindo a vazão em litros por minuto e litros por hora, além de informar o volume total de água que passou pelo sensor desde o início do sistema. 

## Documentação do Código

O código pode ser acessado através desse [link](https://github.com/LauraMWerneck/Projeto_Integrador_3/blob/main/Etapa%203/Sensor%20de%20Vaz%C3%A3o/sensor_vazao.c).

### Dependências/Bibliotecas Incluídas:
- `<stdio.h>`: Para funções de entrada e saída (ex.: `printf`).
- `<stdint.h>`: Para tipos de dados de largura fixa (ex.: `uint32_t`).
- `<stdbool.h>`: Para uso do tipo `bool`.
- `freertos/FreeRTOS.h` e `freertos/task.h`: Para usar o sistema operacional FreeRTOS, que permite multitarefa.
- `driver/gpio.h`: Para manipular pinos GPIO do ESP32.
- `esp_timer.h`: Para operações relacionadas a temporização.

### Constantes
- `YFS201_PIN`: Define o pino GPIO usado para conectar o sensor (GPIO_NUM_4).
- `PULSOS_POR_LITRO`: Especifica o número de pulsos gerados pelo sensor YF-S201 por litro de água (450 pulsos/litro).

### Variáveis Globais
- `contador_pulsos`: Variável volátil que armazena o número de pulsos detectados pelo sensor. É declarada como `volatile` porque seu valor pode ser alterado pela interrupção.

### Funções

- `contar_pulsos(void* arg)`: Função de interrupção que incrementa o contador de pulsos toda vez que o sensor gera um sinal. É declarada como `IRAM_ATTR` para garantir execução rápida diretamente na RAM. Seu comportamento baseia-se em incrementa a variável `contador_pulsos`.

- `setup_gpio()`: Configura o GPIO usado pelo sensor e registra a função de interrupção.
 
- `medir_vazao()`: Calcula a vazão e o volume total de água, exibindo os resultados em intervalos regulares. Essa função salva e reseta o valor do contador de pulsos a cada intervalo, além de aguardar o tempo definido em `intervalo_segundos` antes de calcular a vazão. O cálculo da vzão é medido pela seguinte fórmula:

Vazão (L/min) = (pulsos/tempo)*(60/PULSOS_POR\LITRO)
    
A Vazão (L/h) é calculada pela multiplicação da vazão em L/min por 60, e o volume total pela soma do volume incremental ao longo do tempo. Ao final dos cálculos a função exibe os resultados no terminal usando `printf`.

- `app_main()`: Função principal executada ao iniciar o microcontrolador. Ela configura o GPIO do sensor com `setup_gpio()` e inicia o cálculo contínuo de vazão com `medir_vazao()`.

### Fluxo do Programa
1. Configura o GPIO e registra a interrupção para o sensor.
2. Em `medir_vazao()`, realiza os seguintes passos continuamente:
   - Coleta e reseta o número de pulsos detectados.
   - Aguarda um intervalo de tempo fixo (1 segundo).
   - Calcula a vazão em L/min e L/h, bem como o volume acumulado.
   - Imprime os resultados.
   
### Saída
Durante a execução, o programa exibe no terminal:
- Vazão em Litros por Minuto (L/min).
- Vazão em Litros por Hora (L/h).
- Volume total acumulado em Litros.

Abaixo está uma imagem ilustrando como os dados são exibidos no monitor serial:

monitor_serial

## Resultados Obtidos com o Teste

Inicialmente, o teste foi realizado alimentando o sensor com 3.3V, porém, notamos que nessa condição ele não apresentava uma calibração precisa. Por isso, decidimos realizar o teste utilizando 5V, conforme indicado e recomendado no datasheet do sensor. Ao usar 5V como fonte de alimentação, o sensor funcionou perfeitamente. Para fornecer os 5V necessários, utilizamos um módulo conversor de tensão DC/DC Step-Up.

Para realizar o teste, utilizou-se o sistema físico de teste construído, composto por dois baldes, uma bomba de água e tubulações. O sistema funciona da seguinte maneira: o balde inferior, cheio de água, alimenta a bomba que, por meio de uma mangueira conectada ao sensor, bombeia a água. Após passar pelo sensor, a água é conduzida por outra mangueira que a despeja no balde superior.

Os baldes utilizados possuem marcações para indicar seus volumes. O teste foi iniciado com o balde superior contendo 1 litro de água. Quando o sensor foi ativado pela passagem de água bombeada, enchemos o balde até atingir a marcação de 4 litros. Como o balde já possuía 1 litro inicialmente, a quantidade de água que passou pelo sensor foi de 3 litros. O valor exibido no monitor serial confirmou essa quantidade, validando o funcionamento do sensor e demonstrando que ele está devidamente calibrado. Um vídeo gravado mostrando esse teste é apresentado abaixo:

[Uploading teste_sensor_vazao.mp4…](https://github.com/user-attachments/assets/98108d65-120a-46fe-bbd0-550aa3028449)

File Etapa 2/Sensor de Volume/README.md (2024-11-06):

# Sensor de Volume (Nível) com Sensor Ultrassônico HC-SR04

## Descrição do Sensor
O HC-SR04 é um sensor ultrassônico muito utilizado para medir distâncias em diversos projetos de automação, como sistemas de controle de nível de líquidos. Ele emite ondas ultrassônicas que, ao se chocarem com a superfície do líquido, retornam ao sensor, permitindo calcular a distância entre o sensor e a superfície da água. Este sensor é uma solução econômica, eficiente e de fácil integração com microcontroladores, sendo ideal para projetos de monitoramento e controle de nível de água em reservatórios e caixas d'água.

**Figura 1:** Sensor Ultrassônico HC-SR04.

Sensor Ultrassônico HC-SR04

Fonte: [BOSTON TREINAMENTOS](https://www.bosontreinamentos.com.br/eletronica/arduino/usando-um-sensor-ultrassonico-hc-sr04-com-arduino/).

### Especificações Técnicas
- **Distância de Medição**: 2 cm a 4m (adequado para medir a altura da água em uma caixa ou reservatório).
- **Tensão de Operação**: 5V DC.
- **Consumo de Corrente**: 15 mA (em operação).
- **Precisão**: ± 3 mm.
- **Frequência de Emissão**: 40 kHz.
- **Pinos de Conexão**: 4 pinos (VCC, GND, Trigger e Echo).
- **Temperatura de Operação**: -15°C a 70°C.

### Estrutura e Componentes
O HC-SR04 possui:

**VCC** – Alimentação do sensor (5V)

**GND** – Comum (Ground)

**Trig** – Trigger (disparo), pino usado para transmitir um pulso de ultrassom

**Echo** – Eco, pino que recebe e detecta o pulso de ultrassom refletido por um obstáculo

### Funcionamento no Controle de Nível de Água
O sensor HC-SR04 pode ser facilmente integrado em sistemas de controle de nível de água para monitorar a altura da água em uma caixa ou reservatório. O sensor é posicionado na parte superior do reservatório, voltado para baixo, de modo que as ondas ultrassônicas emitidas pelo sensor se refletem na superfície da água. A partir do tempo de retorno dessas ondas, é possível calcular a distância até o nível da água.

O cálculo da distância é feito pela fórmula:

Distância (cm) = (Tempo de Reflexão (µs) * Velocidade do Som)/2

A partir da distância medida, o sistema pode calcular o nível da água dentro da caixa ou reservatório. Como exemplo, se a caixa tem 2 metros de altura e a distância medida pelo sensor é de 1 metro, o nível de água está em 50% da capacidade total.

**Figura 3:** Funcionamento do Sensor HC-SR04.

Funcionamento do Sensor HC-SR04

Fonte: [MAKER HERO](https://www.makerhero.com/blog/sensor-ultrassonico-hc-sr04-ao-arduino/).

### Aplicações no Controle de Nível
- **Controle Automático de Nível**: O HC-SR04 pode ser usado para automatizar o processo de enchimento ou esvaziamento de reservatórios, evitando transbordamentos ou falta d'água.
- **Monitoramento Remoto**: Integrado com um microcontrolador e um sistema de comunicação (como Wi-Fi ou GSM), o sensor pode enviar informações sobre o nível de água para um servidor ou aplicativo, permitindo o monitoramento remoto do sistema.
- **Alertas e Alarmes**: O sensor pode ser utilizado para disparar alertas ou alarmes quando o nível da água atinge um ponto crítico, como muito baixo (risco de faltar água) ou muito alto (risco de transbordamento).

### Vantagens do Uso do HC-SR04 para Controle de Nível
- **Sem Contato Físico com a Água**: O sensor ultrassônico mede a distância sem precisar entrar em contato direto com o líquido, evitando desgaste e corrosão.
- **Baixo Custo**: O HC-SR04 é uma solução de baixo custo, ideal para projetos de baixo orçamento ou em larga escala.
- **Facilidade de Implementação**: Com apenas 4 pinos e simples integração com microcontroladores, o HC-SR04 é fácil de configurar e utilizar.
- **Alta Precisão**: O sensor oferece uma boa precisão, com variação de apenas 3 mm, tornando-o adequado para controle de nível de água em sistemas pequenos ou médios.

## Referências
BOSTON TREINAMENTOS. **Usando um sensor ultrassônico HC-SR04 com Arduino**. Disponível em: https://www.bosontreinamentos.com.br/eletronica/arduino/usando-um-sensor-ultrassonico-hc-sr04-com-arduino/. Acesso em: 1 nov. 2024.

MAKER HERO. **Sensor ultrassônico HC-SR04 ao Arduino**. Disponível em: https://www.makerhero.com/blog/sensor-ultrassonico-hc-sr04-ao-arduino/. Acesso em: 1 nov. 2024.

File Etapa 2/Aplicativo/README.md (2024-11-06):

# Fórmulas matemáticas do aplicativo

### O microcontrolador irá retornar os seguintes valores para o backend do aplicativo:



### O usuário insere os seguintes valores através da conta de água: 



Assim conseguimos saber o custo da água na região que o usuário irá utilizar o produto.

## Áreas do aplicativo e seus devidos cálculos

### Consumo em Reais (ajustado de acordo com a hora e data):



### Água disponível na caixa d’água:



### Consumo real (diferença em reais com o valor do Hidrômetro):



### Caso acabe a água, tempo de água disponível:

Cálculo feito no consumo normal com base no consumo dos últimos 3 dias: 



### Expectativa de consumo para próximo mês (disponível apenas depois do primeiro mês de uso): 



Esse erro é baseado nos gastos de água da cidade durante o ano, ou nos últimos 6 meses do usuário, ou o mais confiável nos últimos 12 meses do usuário.

### Quanto você gostaria de gastar no próximo mês? (disponível apenas depois do primeiro mês de uso): 



### Limitar aviso (notificar excesso de gasto) e próxima manutenção (Notificar dia da próxima manutenção) não precisam de fórmulas.

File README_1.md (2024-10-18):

# Projeto Integrador III - Monitoramento de Consumo de Água

Este projeto visa desenvolver um sistema completo para monitoramento e controle do consumo de água em caixas d'água. Utilizando sensores de vazão e volume, o sistema fornecerá dados sobre a quantidade de água disponível e utilizada, permitindo ao usuário gerenciar melhor seus recursos hídricos.

## Objetivo

O objetivo principal é criar um dispositivo capaz de:
- Monitorar o volume de água disponível na caixa d'água.
- Medir a vazão de água que entra no sistema.
- Fornecer informações sobre o consumo de água ao longo do tempo (diário, semanal e mensal).
- Avisar o usuário sobre a necessidade de manutenção e limpeza da caixa d'água.
- Estimar o tempo restante de água disponível em caso de falta de abastecimento, com base nos dados de consumo anteriores.

## Funcionalidades

- **Sensores**:
  - **Sensor de Vazão**: Mede o fluxo de água que entra na caixa d'água, permitindo identificar possíveis interrupções no abastecimento ou desperdícios.
  - **Sensor de Volume**: Mede o nível de água presente na caixa d'água, garantindo o acompanhamento contínuo do volume disponível.
  
- **Controle de Consumo**: Os dados são integrados a um aplicativo, onde o usuário poderá visualizar seu consumo de água em diferentes períodos (diário, semanal, mensal), e comparar com os dados do hidrômetro.

- **Estimativa de Consumo**: Em casos de falta de água, o sistema estima quanto tempo a água restante na caixa irá durar, com base no consumo médio anterior.

- **Notificações de Manutenção**: Com base no tempo de uso e nos dados de consumo, o sistema pode alertar o usuário sobre a necessidade de limpeza ou manutenção da caixa d'água.

## Componentes do Sistema

- **Microcontrolador**: Responsável pela coleta e processamento dos dados dos sensores.
- **Sensores de Vazão e Volume**: Para monitoramento da entrada de água e volume na caixa d'água.
- **Aplicativo**: Interface para o usuário acompanhar o consumo e obter notificações.

## Uso

O usuário poderá instalar o equipamento na entrada de sua caixa d'água, conectando os sensores ao sistema. Através do aplicativo, ele poderá acompanhar o consumo de água em tempo real, sendo informado sobre possíveis problemas (falta d'água, necessidade de manutenção) e tomando decisões com base nos dados fornecidos.

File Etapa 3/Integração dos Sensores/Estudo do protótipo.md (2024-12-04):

## Estudo do protótipo

### Impressão 3D
Foram realizadas a modelagem e a impressão 3D de um suporte transversal para manter o medidor de volume exatamente no centro e a 90 graus, melhorando a precisão das medições por proporcionar um ambiente mais controlado. Além disso, foi adicionado um suporte, também impresso em 3D, para posicionar adequadamente a entrada de água.



Fonte: Desenhado no Software Tinkercad.

### Montagem

A entrada de água na caixa d'água foi estendida até o fundo para evitar turbulências na superfície, o que aprimora a medição da distância, garantindo valores de volume mais precisos.

Para a entrada de água proveniente da rua, foi escolhida inicialmente uma válvula de abertura e fechamento por dois motivos principais. O primeiro é assegurar que o sensor de vazão opere apenas durante o enchimento da caixa, evitando a presença de água quando não for necessário, o que previne medições incorretas por retorno de água. O segundo motivo é que a válvula solenoide possui uma peneira integrada, que auxilia na distribuição homogênea da água no cano e mantém a pressão constante.



Fonte: Autoria Própria.

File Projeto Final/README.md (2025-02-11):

# Explicação dos códigos

# [main.c](https://github.com/LauraMWerneck/Projeto_Integrador_3/blob/main/Projeto%20Final/main.c)

O código `main.c` é responsável pelo monitoramento do fluxo de água e do nível de um reservatório utilizando um ESP32. Ele coleta dados 
dos sensores de fluxo e ultrassônico, controla um relé com base nos níveis detectados e envia as informações para um servidor remoto via 
HTTP POST. Além disso, o código gerencia a conexão Wi-Fi, garantindo que o ESP32 esteja sempre conectado para transmitir os dados coletados.

## Funcionalidades
- **Monitoramento do fluxo de água**: Mede a vazão em litros por minuto.
- **Monitoramento do nível de água**: Mede a distância entre o sensor e a superfície da água.
- **Controle de relé**: Ativa ou desativa o relé com base na distância medida pelo sensor ultrassônico.
- **Envio de dados via HTTP POST**: Envia informações para um servidor remoto.

## Coleta de Dados
A coleta de dados ocorre a cada segundo e envolve:
1. **Sensor de Fluxo YF-S201**:
   - O sensor gera pulsos conforme a passagem da água.
   - O ESP32 conta esses pulsos usando uma interrupção no pino `GPIO_NUM_4`.
   - A vazão em litros por minuto é calculada com base nos pulsos.

2. **Sensor Ultrassônico HC-SR04**:
   - Envia um pulso de 10µs pelo pino `TRIG` (`GPIO_NUM_19`).
   - Mede o tempo de resposta do pino `ECHO` (`GPIO_NUM_18`).
   - A distância é calculada a partir do tempo do eco.

3. **Controle do Relé**:
   - Se a distância medida for menor ou igual a 5cm, o relé é ativado (`GPIO_NUM_23`).
   - Se não houver fluxo de água, um alerta de falta de água é ativado.

## Conexão Wi-Fi
O ESP32 se conecta a uma rede Wi-Fi para envio de dados. O processo envolve:
1. **Inicialização do NVS (Non-Volatile Storage)** para armazenar credenciais.
2. **Criação da interface Wi-Fi no modo STA (estação)**.
3. **Configuração das credenciais Wi-Fi**:
   ```c
   #define WIFI_SSID "NomeDaRede"
   #define WIFI_PASS "SenhaDaRede"
   ```
4. **Conexão automática** com a rede configurada.
5. **Monitoramento da conexão** para reconectar em caso de falha.

## Envio de Dados
Os dados coletados são enviados para um servidor HTTP configurado na seguinte URL:
```c
#define SERVER_URL "http://192.168.0.103:5000/ESP_data"
```

O envio ocorre a cada 60 segundos e segue estes passos:
1. Os dados são formatados em um JSON:
   ```c
   snprintf(payload, sizeof(payload), 
   "{\"flow_rate\":%.2f,\"total_volume\":%.2f,\"distance\":%.2f,\"volume_minuto\":%.2f, \"falta_agua\":%d}",
   vazao, volume_total, distancia, volume_por_minuto, falta_agua);
   ```
2. O ESP32 realiza uma requisição HTTP POST com o JSON.
3. O servidor responde confirmando o recebimento.
4. Em caso de falha, o erro é registrado nos logs para depuração.

## Estrutura do Código
1. **Configuração dos pinos** para sensores e relé.
2. **Configuração do Wi-Fi** para conexão com a rede.
3. **Função de medição de distância** com o sensor ultrassônico.
4. **Função de contagem de pulsos** do sensor de fluxo.
5. **Monitoramento em loop**:
   - Mede vazão e volume de água.
   - Mede a distância do nível de água.
   - Controla o relé com base no nível.
   - Envia dados para o servidor a cada minuto.

## Logs e Depuração
O ESP32 exibirá logs via serial, como por exemplo:
```sh
Vazão: 1.25 L/min, Volume Total: 2.50 L, Distância: 10.2 cm, Falta água: 0
```
Caso haja falha no envio HTTP, uma mensagem de erro será exibida.

# [app.py](https://github.com/LauraMWerneck/Projeto_Integrador_3/blob/main/Projeto%20Final/app.py)

O código `app.py` é responsável por criar e configurar uma API web utilizando o framework Flask. Essa API é projetada para se comunicar com um sistema de monitoramento de consumo de água e controle de caixa d'água, permitindo tanto o envio de dados do sensor quanto o recebimento e armazenamento de configurações de consumo de água. A aplicação também realiza cálculos relacionados ao consumo, como o custo da água, tempo estimado de consumo, e alertas de falta d'água, além de fornecer esses dados para um painel de visualização em tempo real no frontend.

## Funcionalidades

1. **Recepção de Dados de Sensores (`/ESP_data`)**  
   A rota `/ESP_data` recebe dados de sensores (como distância, volume de água consumido, e taxa de vazão), realiza o processamento e armazena essas informações em arquivos. Além disso, calcula o consumo de água em reais, faz a comparação entre o consumo registrado e o hidrometro, calcula o tempo estimado de água disponível na caixa d'água e gera alertas caso a falta de água seja detectada.

2. **Cadastro de Configurações do Sistema (`/save_data`)**  
   A rota `/save_data` permite o envio de configurações para o sistema, como consumo do hidrômetro, custo da água, e o volume da caixa d'água. Esses dados são armazenados em um arquivo JSON chamado `dados.txt`.

3. **Stream de Logs para o Frontend (`/logs_stream`)**  
   A aplicação utiliza Server-Sent Events (SSE) para enviar logs em tempo real para o frontend, permitindo a atualização constante dos dados sem a necessidade de reatualizar a página.

4. **Leitura de Dados de Arquivo (`dados.txt`)**  
   O sistema realiza a leitura do arquivo `dados.txt` para obter os valores de consumo, custo e volume da caixa d'água. Se o arquivo não existir, ele será criado com valores padrão.

## Estrutura de Arquivos

- **`dados.txt`**: Armazena as configurações do sistema, como consumo do hidrômetro, custo da água, volume da caixa d'água, e outros dados relevantes.
- **`contador.txt`**: Mantém o valor do contador para garantir o controle dos dados mensais.
- **`valores.txt`**: Armazena os valores do volume de água consumido por minuto e por hora.
- **`logs`**: Armazena logs gerados pela aplicação que são enviados ao frontend via SSE.

## Endpoints

- **`POST /ESP_data`**: Envia dados do sensor (distância, volume, vazão).
- **`POST /save_data`**: Envia configurações do sistema (consumo do hidrômetro, custo da água, etc.).
- **`GET /logs_stream`**: Recupera os logs em tempo real via SSE.

## Dados Esperados

- Para a rota `/ESP_data`:
  - **Exemplo de dados**:
    ```json
    {
      "distance": 10.5,
      "volume_minuto": 1.25,
      "flow_rate": 0.5,
      "total_volume": 100,
      "falta_agua": 0
    }
    ```

- Para a rota `/save_data`:
  - **Exemplo de dados**:
    ```json
    {
      "consumoHidrometro": 5.2,
      "custoAgua": 15.5,
      "ultimoCusto": 10.25,
      "gastoFuturo": 18.0,
      "volumeCaixa": 500
    }
    ```

## Cálculos Realizados

1. **Cálculo de Custo por Litro de Água**  
   O custo por litro de água é calculado dividindo o custo total da água pelo consumo registrado no hidrômetro.

2. **Cálculo de Consumo por Minuto e Hora**  
   O consumo de água é registrado por minuto e por hora, com a conversão para o custo correspondente em reais.

3. **Detecção de Falta de Água**  
   Caso a distância medida seja muito baixa (indicando que a caixa d'água está vazia), o sistema gera um alerta de falta de água.

4. **Estimativa de Tempo de Água Disponível**  
   A partir da medição de volume na caixa d'água e da média de consumo diário, é calculado quanto tempo o restante da água disponível será suficiente.

# [index.html](https://github.com/LauraMWerneck/Projeto_Integrador_3/blob/main/Projeto%20Final/index.html)

O código `index.html` é responsável por criar uma interface visual interativa para o monitoramento de recursos, especialmente focado no consumo de água. Ele permite que o usuário visualize informações sobre o consumo de água, o custo associado a esse consumo e os alertas relacionados à falta de água. Além disso, a página também permite o registro inicial de dados e a atualização mensal dessas informações.

## Funcionalidades Principais

- **Monitoramento em tempo real**: A interface se conecta a um servidor para receber dados de monitoramento em tempo real, como o consumo de água por minuto e por hora, além de informações sobre o custo associado ao consumo.
  
- **Exibição de Gráficos**: Utiliza a biblioteca `Chart.js` para gerar gráficos de barras que visualizam o consumo de água ao longo do tempo, seja por minuto, por hora ou por dia. O usuário pode alternar entre diferentes tipos de gráficos clicando no botão de alternância.

- **Logs de Alertas**: O código também exibe logs de alertas relacionados ao consumo, como avisos de falta de água ou discrepâncias entre o consumo real e o esperado.

- **Cadastro Inicial e Atualização Mensal**: O usuário pode inserir dados de consumo e custos no início e ao longo dos meses, para registrar o consumo de água e o custo total, bem como definir metas de consumo para o mês seguinte.

## Estrutura da Página

### Cabeçalho
- Contém o título "Monitoramento de Recursos" e um ícone representativo do sistema.

### Corpo Principal
- **Primeira Coluna**: Contém a seção "Painel", que exibe logs de alertas (como falta de água e discrepâncias de consumo) e a seção de gráficos, que mostra os dados de consumo de água.
  
- **Segunda Coluna**: Contém o gráfico de consumo de água gerado dinamicamente.

### Formulário de Cadastro
- O usuário pode inserir dados relacionados ao consumo de água, custo e volume da caixa d'água, além de informar o custo do último mês e o valor desejado para o gasto futuro.

## Funcionalidade de Logs

O sistema possui um mecanismo para exibir logs em tempo real relacionados a:
- **Falta de Água**: Um alerta é exibido quando a água está em falta ou quando o volume disponível não é suficiente para o consumo esperado.
- **Diferença de Consumo**: Caso haja uma diferença significativa entre o consumo real e o esperado, um alerta é mostrado.
- **Sugestões de Economia**: O sistema sugere ações para economizar água, com base na porcentagem de diferença de consumo.

## Interatividade

O usuário pode interagir com o sistema de várias maneiras:
- **Alternar entre gráficos**: O botão "🔄 Alternar" permite alternar entre diferentes tipos de gráficos, como consumo por minuto, por hora, custo por minuto, entre outros.
- **Alternar entre logs**: O botão "🔄 Alternar" da seção de logs alterna entre os estados de log para exibir informações como alerta de falta de água ou discrepâncias de consumo.

## Envio de Dados

O sistema envia os dados inseridos pelo usuário para uma API backend. Quando o botão "Salvar e Enviar" é pressionado, os dados de consumo, custo, volume da caixa d'água e outras informações são enviados para o servidor para serem processados.

## Bibliotecas Utilizadas

- **Chart.js**: Usado para renderizar gráficos dinâmicos baseados nos dados recebidos.
  
## API Backend

A comunicação com o backend é feita via requisição `POST` para a URL `http://localhost:5000/save_data`, enviando os dados inseridos pelo usuário. O backend também fornece dados em tempo real via `EventSource`, o que permite atualizar a interface com os logs e gráficos de consumo.

## Como Funciona

1. **Conexão com o Backend**: Ao carregar a página, a aplicação estabelece uma conexão com o servidor através do `EventSource`, recebendo dados sobre o consumo de água e atualizando a interface conforme necessário.

2. **Exibição de Dados**: O gráfico de consumo e os logs são atualizados automaticamente quando novos dados são recebidos do servidor.

3. **Interação com o Usuário**: O usuário pode fornecer entradas no formulário para cadastrar dados iniciais ou atualizar informações mensais, que são então enviados para o servidor via requisição `POST`.

4. **Gráficos Dinâmicos**: O sistema permite alternar entre diferentes tipos de gráficos para visualizar o consumo de água ao longo do tempo, o custo associado e outras métricas de interesse.

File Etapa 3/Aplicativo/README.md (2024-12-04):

## Aplicativo - Etapa 3

  No aplicativo, foi estabelecida a comunicação entre o backend(app.py) e o frontend(index.html) por meio de uma API. O usuário insere os valores necessários para os cálculos, organizados em duas áreas principais:  

### Cadastro inicial:
- Inserção do volume de água consumido no mês, conforme indicado na conta de água, em m³.  
- Inserção do valor total gasto com água no mês, em reais.  
  - Essas informações são utilizadas para calcular o custo médio da água na região.  
- Também é solicitado o volume da caixa d'água, em litros.  

### Atualização mensal:
- Inserção do valor da conta de água no mês atual, em reais. 
  - Comparação entre as leituras do hidrômetro e as medições do equipamento desenvolvido.  
- Inserção de uma expectativa de consumo para o próximo mês, em reais.
  - Permitindo estimar o quanto o usuário deve economizar para alcançar seu objetivo.



Fonte: Autoria Própria.

### Esses dados são enviados para o backend, onde são armazenados em variáveis para cálculos, são eles: 
- Consumo em reais (por hora, dia, mês e ano).  
- Consumo real (diferença em reais entre o valor do hidrômetro e o equipamento).
- Tempo de água disponível na caixa d'água.

Atualmente, esses dados são exibidos no terminal do VS Code. A proposta é apresentar essas informações diretamente ao usuário por meio do frontend.



Fonte: Autoria Própria.

Ainda estão pendentes algumas funcionalidades descritas na etapa 2 que serão feitas pela etapa 4 pois é necessário a implementação completa de todos os módulos do equipamento. Os próximos passos incluem receber e processar os dados enviados pelo microcontrolador e retornar as informações processadas para a interface do usuário.

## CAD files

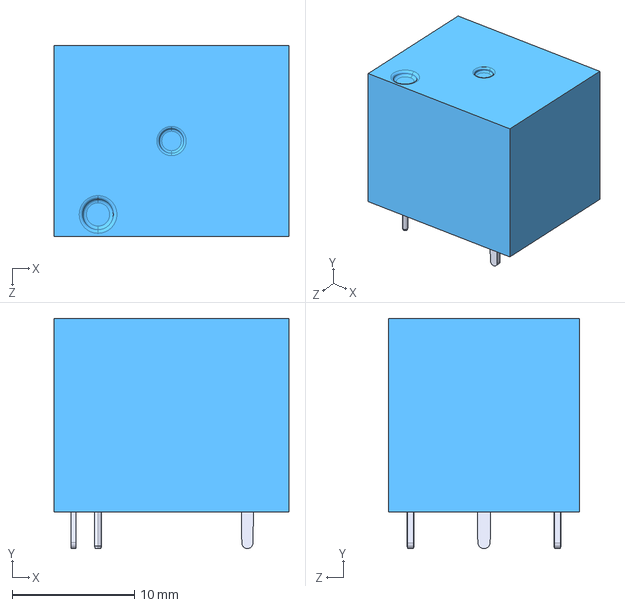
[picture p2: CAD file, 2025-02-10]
Projeto Final/Placa/Projeto Placa PI3/SRD-05VDC-SL-C/SRD-05VDC-SL-C.step
19.2 x 18.8 x 15.6 mm

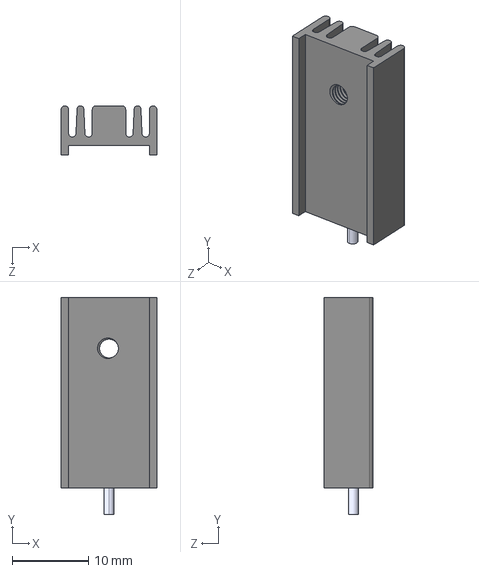
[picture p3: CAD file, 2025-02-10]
Projeto Final/Placa/Projeto Placa PI3/SK 95 25 STS TO 220--3DModel-STEP-269445.STEP
12.6 x 28.5 x 6.50 mm

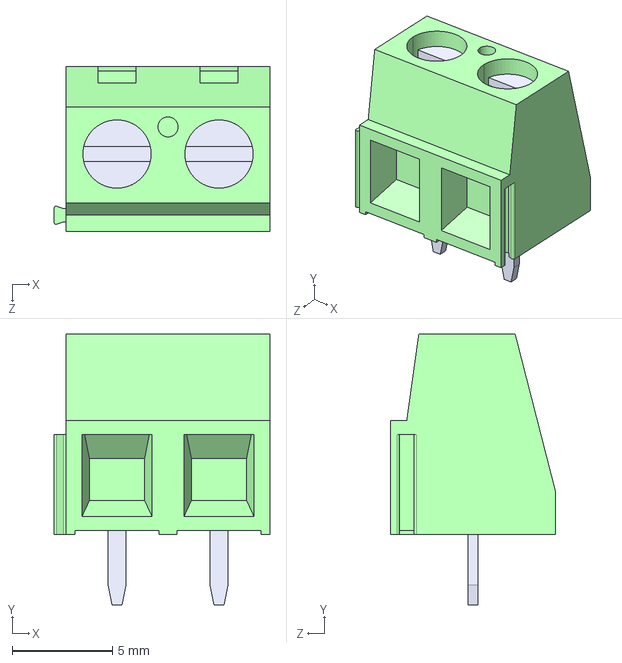
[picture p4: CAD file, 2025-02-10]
Projeto Final/Placa/Projeto Placa PI3/282837-2--3DModel-STEP-269445.STEP
10.8 x 13.5 x 8.20 mm

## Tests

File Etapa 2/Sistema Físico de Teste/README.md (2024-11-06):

# Descrição de Como o Sistema Físico de Teste Vai Ser Montado

Para este sistema de teste, serão utilizados três componentes principais: um sensor de vazão, uma válvula solenoide e um sensor ultrassônico. A placa ESP atuará como controlador, gerenciando as informações dos sensores e acionando a válvula conforme necessário. 

O sistema físico será composto por uma mangueira transparente conectada ao registro de água. Nessa mangueira, estarão acoplados uma válvula solenóide e o sensor de vazão YF-S201, ambos fixados por uma peça impressa em 3D, projetada para otimizar o desempenho e o controle do fluxo de água. Após o sensor, haverá outra mangueira que levará a água até um balde, representando a caixa d'água. Na parte inferior desse balde, será instalada uma válvula de saída para simular a vazão de água da caixa d'água. 

Um ponto importante é que o balde terá uma tampa, onde será montado o sensor de volume (sensor ultrassônico). Além disso, teremos um segundo balde para escoar a água que sair do balde principal durante os testes de variação de volume.

## Diagrama do Sistema de Teste

A figura abaixo representa o diagrama deblocos do sistema de teste. 

**Figura 1**: Diagrama do sistema físico de teste.

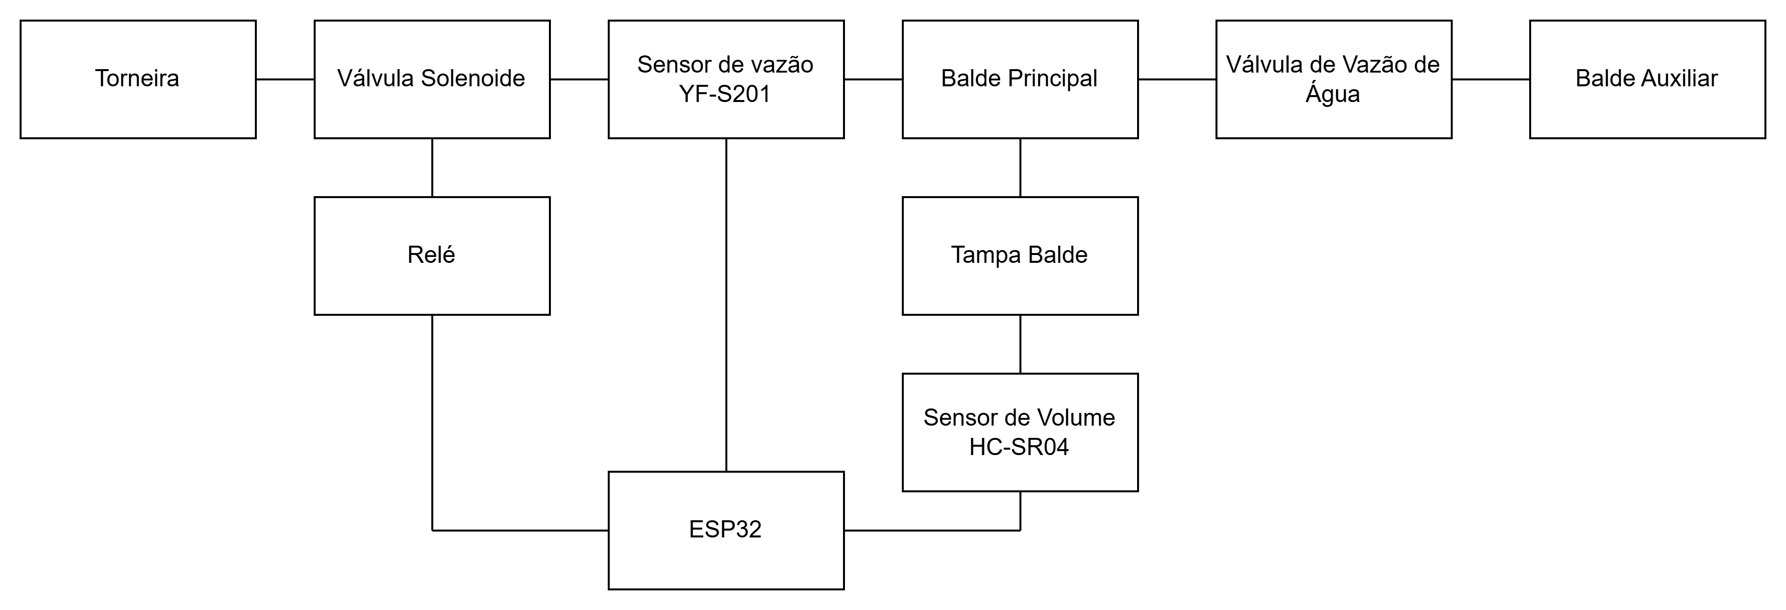
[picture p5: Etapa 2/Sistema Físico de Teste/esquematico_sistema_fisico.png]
Diagrama do sistema físico de teste.


Fonte:Autoria própria.

## Esboço do Sistema de Teste

A figura abaixo representa o esboço do sistema de teste com a disposição dos componentes e a conexão com a ESP. 

**Figura 2**: Esquema do sistema físico de teste.

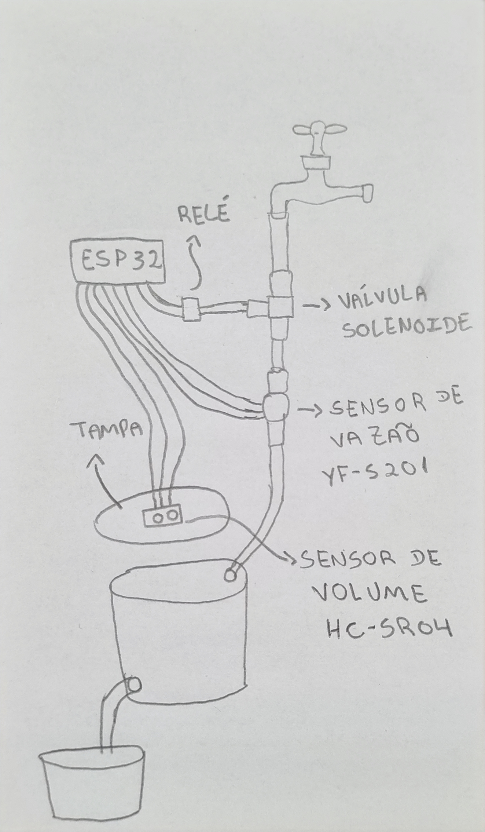
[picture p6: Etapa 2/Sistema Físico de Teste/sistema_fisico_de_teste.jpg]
Esquema do sistema físico de teste.


Fonte:Autoria própria.

## Para modelagem 3D utilizada no sistema:

A ideia inicial era conectar a válvula solenoide ao sensor de vazão utilizando um conector fêmea-fêmea comum de ½ polegada. No entanto, identificamos uma diferença significativa nos diâmetros internos: 15 mm para a válvula e 11 mm para o sensor. Utilizar um conector de encanamento padrão poderia ampliar ainda mais essa discrepância devido ao espaço interno da peça.

Diante disso, percebemos a importância de minimizar essa diferença abrupta nos diâmetros internos, visando reduzir o risco de cavitação — um fenômeno que gera bolhas de ar nos canos, potencialmente comprometendo a precisão das medições do sensor de vazão.

Para solucionar esse problema, projetamos uma peça personalizada, especificamente modelada para acomodar a variação nos diâmetros internos. A peça foi impressa em 3D, levando em consideração o tamanho total das roscas e os diâmetros internos de cada componente, garantindo uma transição mais suave e eficiente.



## Exemplo de Componentes

**1. Balde:**

JAGUAR UTILIDADES. **Balde com tampa 72L alça plástica industrial**. Disponível em: https://jaguarutilidades.com.br/produto/3014-balde-com-tampa-72l-alca-plastica-industrial/. Acesso em: 30 out. 2024.

**2. Mangueira:**

PADRÃO MANGUEIRAS. **Mangueira plástica cristal**. Disponível em: https://padraomangueiras.com.br/produto/mangueira-plastica-cristal/. Acesso em: 30 out. 2024.

**3. Torneira/Válvula de Saída:**

MULTIFRIO SHOP. **Torneira premium com conector para bebedouro branco/azul**. Disponível em: https://www.multifrioshop.com/pecas-para-bebedouro/torneiras/torneira-premium-com-conector-para-bebedouro-brancoazul. Acesso em: 30 out. 2024.

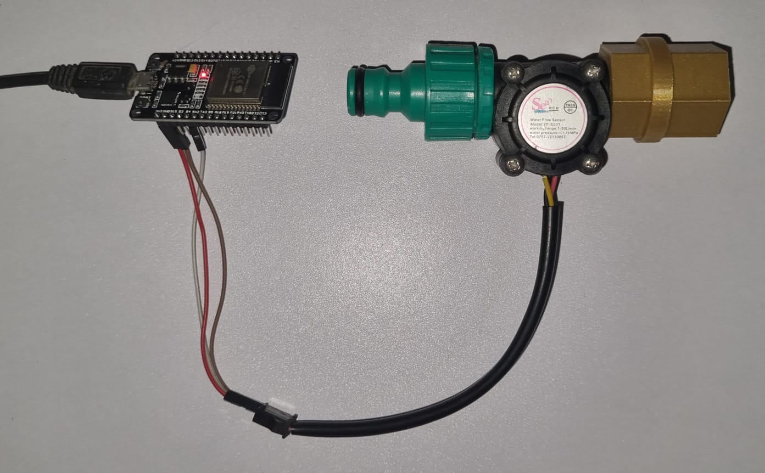
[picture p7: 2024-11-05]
Etapa 2/Sensor de Vazão/Teste de Firmware/conexao_esp_yfs201.jpg

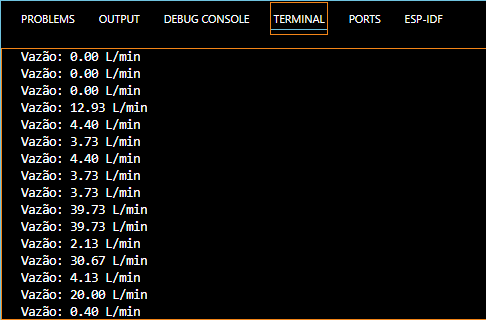
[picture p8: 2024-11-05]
Etapa 2/Sensor de Vazão/Teste de Firmware/monitor_serial.png

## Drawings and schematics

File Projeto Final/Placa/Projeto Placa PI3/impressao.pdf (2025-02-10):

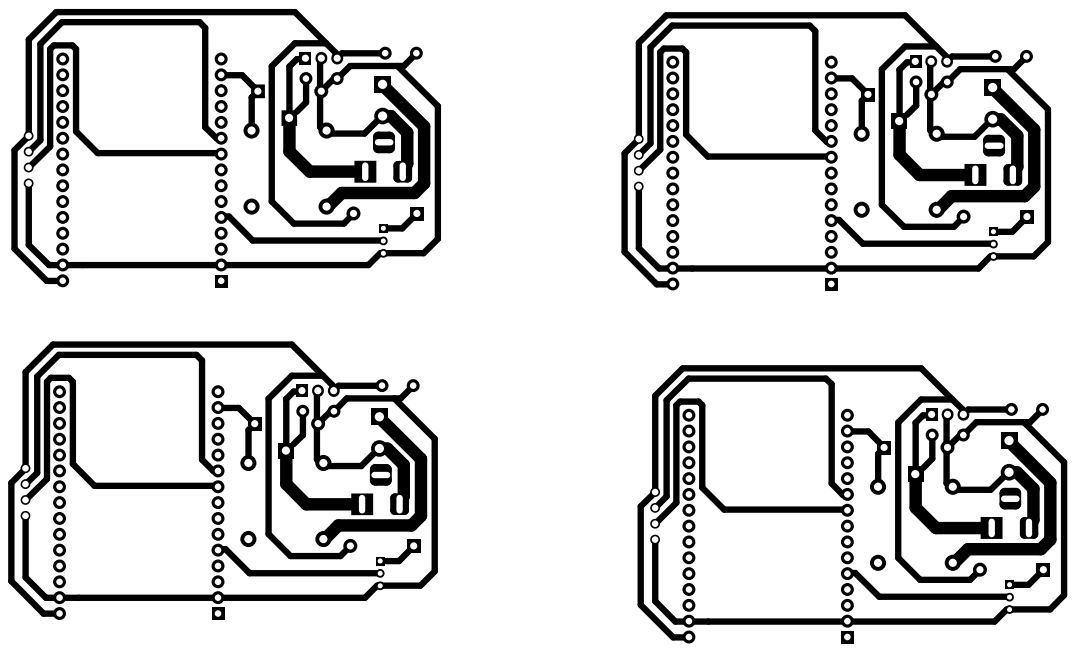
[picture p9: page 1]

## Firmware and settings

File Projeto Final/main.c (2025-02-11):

#include <stdio.h>
#include <stdint.h>
#include <stdbool.h>
#include <string.h>
#include "freertos/FreeRTOS.h"
#include "freertos/task.h"
#include "driver/gpio.h"
#include "esp_timer.h"
#include "esp_log.h"
#include "esp_wifi.h"
#include "esp_event.h"
#include "nvs_flash.h"
#include "esp_http_client.h"

// Configurações dos sensores
#define YFS201_PIN GPIO_NUM_4           // Pino conectado ao sensor de fluxo YF-S201
#define PULSOS_POR_LITRO 450            // Número de pulsos que correspondem a 1 litro de fluxo
#define ULTRASONIC_TRIG_PIN GPIO_NUM_19 // Pino TRIG do sensor ultrassônico
#define ULTRASONIC_ECHO_PIN GPIO_NUM_18 // Pino ECHO do sensor ultrassônico
#define RELE_PIN GPIO_NUM_23            // Pino do relé
#define TIMEOUT_US 25000                // Tempo máximo de espera para leitura do sensor ultrassônico

// Credenciais Wi-Fi
#define WIFI_SSID "TP-Link_A25C"      // Nome da rede Wi-Fi
#define WIFI_PASS "********"          // Senha da rede Wi-Fi

// URL do servidor Python
// OBS: é preciso dar um ping e ver o endereço do IPV4 e colocar ele como o IP antes de :50000/ESP_data
#define SERVER_URL "http://192.168.0.103:5000/ESP_data" // Endereço do backend

// Variáveis globais
volatile uint32_t contador_pulsos = 0; // Variável que armazena a contagem de pulsos do sensor de fluxo
int falta_agua = 0;
static const char *TAG = "Main";       // Tag para exibição de logs

// Função de interrupção para o sensor YF-S201
static void IRAM_ATTR contar_pulsos(void *arg) {
    contador_pulsos++; // Incrementa o contador de pulsos toda vez que o sensor gera um pulso
}

// Configuração do GPIO para o sensor YF-S201
void setup_yfs201_gpio() {
    gpio_config_t io_conf = {              // Configura o pino do sensor como entrada com interrupção
        .intr_type = GPIO_INTR_POSEDGE,    // Interrupção no flanco de subida
        .mode = GPIO_MODE_INPUT,           // Configuração como entrada
        .pin_bit_mask = (1ULL << YFS201_PIN) // Máscara do pino
    };
    gpio_config(&io_conf);                 // Aplica as configurações
    gpio_install_isr_service(0);           // Inicializa o serviço de interrupções
    gpio_isr_handler_add(YFS201_PIN, contar_pulsos, NULL); // Associa a interrupção ao pino
}

// Inicializa o Wi-Fi
void wifi_init(void) {
    esp_err_t ret = nvs_flash_init(); // Inicializa o sistema de armazenamento não volátil
    if (ret == ESP_ERR_NVS_NO_FREE_PAGES || ret == ESP_ERR_NVS_NEW_VERSION_FOUND) {
        ESP_ERROR_CHECK(nvs_flash_erase()); // Apaga o armazenamento se necessário
        ret = nvs_flash_init();
    }
    ESP_ERROR_CHECK(ret);

    ESP_LOGI(TAG, "Inicializando Wi-Fi...");
    ESP_ERROR_CHECK(esp_netif_init()); // Inicializa a interface de rede
    ESP_ERROR_CHECK(esp_event_loop_create_default()); // Cria o loop de eventos padrão
    esp_netif_create_default_wifi_sta(); // Cria uma interface Wi-Fi no modo estação

    wifi_init_config_t cfg = WIFI_INIT_CONFIG_DEFAULT(); // Configurações padrão de inicialização
    ESP_ERROR_CHECK(esp_wifi_init(&cfg)); // Inicializa o módulo Wi-Fi

    wifi_config_t wifi_config = {         // Configura as credenciais Wi-Fi
        .sta = {
            .ssid = WIFI_SSID,
            .password = WIFI_PASS,
        },
    };
    ESP_ERROR_CHECK(esp_wifi_set_mode(WIFI_MODE_STA)); // Define o modo como estação
    ESP_ERROR_CHECK(esp_wifi_set_config(ESP_IF_WIFI_STA, &wifi_config)); // Aplica as credenciais
    ESP_ERROR_CHECK(esp_wifi_start()); // Inicia o Wi-Fi

    ESP_LOGI(TAG, "Conectando ao Wi-Fi...");
    ESP_ERROR_CHECK(esp_wifi_connect()); // Conecta à rede Wi-Fi
}

// Envia dados via HTTP POST
void send_data(float vazao, float volume_total, float distancia, float volume_por_minuto, bool falta_agua) {
    char payload[256]; // Buffer para armazenar os dados em formato JSON
    snprintf(payload, sizeof(payload), "{\"flow_rate\":%.2f,\"total_volume\":%.2f,\"distance\":%.2f,\"volume_minuto\":%.2f, \"falta_agua\":%d}", vazao, volume_total, distancia, volume_por_minuto, falta_agua);

    esp_http_client_config_t config = { // Configura o cliente HTTP
        .url = SERVER_URL,
        .method = HTTP_METHOD_POST,
    };

    esp_http_client_handle_t client = esp_http_client_init(&config); // Inicializa o cliente HTTP
    esp_http_client_set_header(client, "Content-Type", "application/json"); // Define o cabeçalho como JSON
    esp_http_client_set_post_field(client, payload, strlen(payload)); // Define o corpo da requisição

    esp_err_t err = esp_http_client_perform(client); // Realiza a requisição
    if (err == ESP_OK) {
        ESP_LOGI(TAG, "Dados enviados com sucesso: %s", payload); // Log de sucesso
    } else {
        ESP_LOGE(TAG, "Erro ao enviar dados: %s", esp_err_to_name(err)); // Log de erro
    }

    esp_http_client_cleanup(client); // Libera os recursos do cliente HTTP
}

// Função de inicialização para o sensor ultrassônico
void init_ultrasonic_sensor() {
    gpio_set_direction(ULTRASONIC_TRIG_PIN, GPIO_MODE_OUTPUT); // Configura o pino TRIG como saída
    gpio_set_direction(ULTRASONIC_ECHO_PIN, GPIO_MODE_INPUT);  // Configura o pino ECHO como entrada
}

// Função para medir a distância usando o sensor ultrassônico
float measure_distance() {
    gpio_set_level(ULTRASONIC_TRIG_PIN, 0); // Garante que o TRIG está em nível baixo
    vTaskDelay(2 / portTICK_PERIOD_MS);     // Aguarda 2ms
    gpio_set_level(ULTRASONIC_TRIG_PIN, 1); // Envia um pulso de 10µs no TRIG
    esp_rom_delay_us(10);
    gpio_set_level(ULTRASONIC_TRIG_PIN, 0);

    int64_t start_time = 0, end_time = 0; // Variáveis para medir o tempo do pulso
    int64_t wait_start = esp_timer_get_time();
    while (gpio_get_level(ULTRASONIC_ECHO_PIN) == 0) { // Espera o ECHO subir
        if (esp_timer_get_time() - wait_start > TIMEOUT_US) { // Verifica timeout
            return -1.0; // Retorna erro se ultrapassar o tempo limite
        }
        start_time = esp_timer_get_time();
    }

    wait_start = esp_timer_get_time();
    while (gpio_get_level(ULTRASONIC_ECHO_PIN) == 1) { // Espera o ECHO descer
        if (esp_timer_get_time() - wait_start > TIMEOUT_US) { // Verifica timeout
            return -1.0; // Retorna erro se ultrapassar o tempo limite
        }
        end_time = esp_timer_get_time();
    }

    float duration = (float)(end_time - start_time); // Calcula a duração do pulso
    float distance = (duration * 0.034) / 2; // Calcula a distância em cm
    return distance;
}

// Configuração do GPIO do relé
void setup_relay() {
    gpio_set_direction(RELE_PIN, GPIO_MODE_OUTPUT); // Configura o pino como saída
    gpio_set_level(RELE_PIN, 0); // Começa desligado
}

// Tarefa de monitoramento dos sensores
void sensor_task(void *pvParameters) {
    setup_yfs201_gpio();         // Configura o sensor de fluxo
    init_ultrasonic_sensor();    // Configura o sensor ultrassônico
    setup_relay();

    const float intervalo_segundos = 1.0; // Intervalo de leitura dos sensores (1 segundo)
    float volume_total = 0;               // Volume total acumulado

    while (1) {
        uint32_t pulsos = contador_pulsos; // Copia os pulsos capturados
        contador_pulsos = 0;               // Reseta o contador
        vTaskDelay(pdMS_TO_TICKS(intervalo_segundos * 1000)); // Aguarda o intervalo
        float distancia = measure_distance(); // Mede a distância

        float vazao = (pulsos / intervalo_segundos) * (60.0 / PULSOS_POR_LITRO); // Calcula a vazão em L/min
        float volume = vazao / 60;        // Calcula o volume em litros
        float volume_por_minuto = 0;      // Volume salvo a cada minuto
        volume_total += volume;           // Atualiza o volume total acumulado
        
        // A cada minuto, salva o volume em uma variável
        static int segundos = 0;
        segundos++;
        
        // Se a distância for menor ou igual a 5 cm, liga o relé
        if (distancia > 0 && distancia <= 5) {

            gpio_set_level(RELE_PIN, 1);
            ESP_LOGI(TAG, "Relé ligado!");
            falta_agua = 0;

        } else {
            gpio_set_level(RELE_PIN, 0);
            ESP_LOGI(TAG, "Relé desligado!");

            if (vazao == 0){
                falta_agua = 1;
                ESP_LOGI(TAG, "ALERTA: Falta de água detectada!");
            }else{
                falta_agua = 0;
                ESP_LOGI(TAG, "Tem água!");  
            }
        }

        ESP_LOGI(TAG, "Vazão: %.2f L/min, Volume Total: %.2f L, Distância: %.2f cm, Falta água: %d", vazao, volume_total, distancia, falta_agua);

        if (segundos >= 60) { // Após 60 segundos
            volume_por_minuto = volume_total;       // Salva o volume total no minuto
            printf("Volume salvo a cada minuto: %.2f litros\n", volume_por_minuto);
            ESP_LOGI(TAG, "Volume por minuto: %.2f L", volume_por_minuto);

            send_data(vazao, volume_total, distancia, volume_por_minuto, falta_agua);  
            
            volume_por_minuto = 0;                 // Reseta o volume_por_minuto após exibir
            volume_total = 0;                      // Opcional: Reseta volume_total, se necessário
            segundos = 0;                          // Reseta o contador de segundos
        }
    }
}

// Função principal
void app_main(void) {
    wifi_init(); // Inicializa o Wi-Fi
    xTaskCreate(sensor_task, "sensor_task", 4096, NULL, 5, NULL); // Cria a tarefa de monitoramento dos sensores
}

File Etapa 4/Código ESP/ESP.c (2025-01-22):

#include <stdio.h>                    // Biblioteca padrão para entrada e saída
#include <stdint.h>                   // Tipos de dados inteiros padrão
#include <stdbool.h>                  // Tipos booleanos (true/false)
#include "freertos/FreeRTOS.h"        // Biblioteca do FreeRTOS para gerenciamento de tarefas
#include "freertos/task.h"            // Biblioteca do FreeRTOS para criação de tarefas
#include "driver/gpio.h"              // Biblioteca para manipulação de GPIOs
#include "esp_timer.h"                // Biblioteca para temporizadores de alta precisão
#include "esp_task_wdt.h"             // Biblioteca para o watchdog timer

// Definições de pinos para os sensores
#define ULTRASONIC_TRIG_PIN GPIO_NUM_18  // Pino GPIO para o TRIG do sensor ultrassônico
#define ULTRASONIC_ECHO_PIN GPIO_NUM_19  // Pino GPIO para o ECHO do sensor ultrassônico
#define YFS201_PIN GPIO_NUM_4            // Pino GPIO para o sensor de vazão YF-S201
#define TIMEOUT_US 25000                 // Timeout para medir distância (em microssegundos)

// Configuração do sensor de vazão YF-S201
#define PULSOS_POR_LITRO 450             // Quantidade de pulsos por litro do sensor YF-S201

// Variáveis globais
volatile uint32_t contador_pulsos = 0;    // Contador de pulsos do sensor YF-S201
TaskHandle_t ultrasonicTaskHandle = NULL; // Handle da tarefa do sensor ultrassônico
TaskHandle_t flowTaskHandle = NULL;       // Handle da tarefa do sensor de vazão

// Função de interrupção para o sensor YF-S201 (executada a cada pulso recebido)
static void IRAM_ATTR contar_pulsos(void* arg) {
    contador_pulsos++; // Incrementa o contador de pulsos global
}

// Função de inicialização para o sensor ultrassônico
void init_ultrasonic_sensor() {
    gpio_set_direction(ULTRASONIC_TRIG_PIN, GPIO_MODE_OUTPUT); // Define TRIG como saída
    gpio_set_direction(ULTRASONIC_ECHO_PIN, GPIO_MODE_INPUT);  // Define ECHO como entrada
}

// Função para medir a distância usando o sensor ultrassônico
float measure_distance() {
    // Gera o pulso de TRIG
    gpio_set_level(ULTRASONIC_TRIG_PIN, 0);           // TRIG em nível baixo
    vTaskDelay(2 / portTICK_PERIOD_MS);               // Aguarda 2 ms
    gpio_set_level(ULTRASONIC_TRIG_PIN, 1);           // TRIG em nível alto
    esp_rom_delay_us(10);                             // Mantém o pulso por 10 µs
    gpio_set_level(ULTRASONIC_TRIG_PIN, 0);           // TRIG em nível baixo

    int64_t start_time = 0, end_time = 0;             // Variáveis para armazenar os tempos de subida e descida

    // Aguarda pelo sinal de subida no ECHO (início da medição)
    int64_t wait_start = esp_timer_get_time();        // Tempo atual em microssegundos
    while (gpio_get_level(ULTRASONIC_ECHO_PIN) == 0) {
        if (esp_timer_get_time() - wait_start > TIMEOUT_US) {
            return -1.0; // Retorna -1 em caso de timeout
        }
        start_time = esp_timer_get_time();            // Registra o tempo de início
    }

    // Aguarda pelo sinal de descida no ECHO (fim da medição)
    wait_start = esp_timer_get_time();                // Reinicia o tempo de espera
    while (gpio_get_level(ULTRASONIC_ECHO_PIN) == 1) {
        if (esp_timer_get_time() - wait_start > TIMEOUT_US) {
            return -1.0; // Retorna -1 em caso de timeout
        }
        end_time = esp_timer_get_time();              // Registra o tempo de término
    }

    float duration = (float)(end_time - start_time);  // Calcula a duração do pulso em microssegundos
    float distance = (duration * 0.034) / 2;          // Calcula a distância em centímetros
    return distance;                                  // Retorna a distância medida
}

// Tarefa para o sensor ultrassônico
void ultrasonic_task(void *pvParameters) {
    init_ultrasonic_sensor();                        // Inicializa os pinos do sensor ultrassônico
    esp_task_wdt_add(NULL);                          // Registra a tarefa no watchdog

    while (1) {
        float distance = measure_distance();         // Mede a distância
        if (distance >= 0) {
            printf("Distância: %.2f cm\n", distance);// Imprime a distância medida
        }
        esp_task_wdt_reset();                        // Reseta o watchdog para evitar timeout
        vTaskDelay(pdMS_TO_TICKS(1000));             // Aguarda 1 segundo para a próxima leitura
    }
}

// Função para configurar o GPIO do sensor YF-S201
void setup_yfs201_gpio() {
    gpio_config_t io_conf = {
        .intr_type = GPIO_INTR_POSEDGE,                    // Interrupção na borda de subida
        .mode = GPIO_MODE_INPUT,                           // Define o pino como entrada
        .pin_bit_mask = (1ULL << YFS201_PIN)               // Máscara para selecionar o pino do sensor
    };
    gpio_config(&io_conf);                                 // Aplica as configurações
    gpio_install_isr_service(0);                           // Inicia o serviço de interrupção
    gpio_isr_handler_add(YFS201_PIN, contar_pulsos, NULL); // Adiciona a função de interrupção
}

// Tarefa para medir a vazão de água
void flow_task(void *pvParameters) {
    setup_yfs201_gpio();                          // Configura o GPIO do sensor
    float volume_total = 0;                       // Volume total acumulado
    float volume_por_minuto = 0;                  // Volume salvo a cada minuto
    const float intervalo_segundos = 1.0;         // Intervalo de cálculo (1 segundo)

    while (1) {
        uint32_t pulso_inicial = contador_pulsos; // Captura os pulsos atuais
        contador_pulsos = 0;                      // Reseta o contador
        vTaskDelay(pdMS_TO_TICKS(intervalo_segundos * 1000)); // Delay de 1 segundo

        float vazao_litros_por_minuto = (pulso_inicial / intervalo_segundos) * (60.0 / PULSOS_POR_LITRO);
        float volume = vazao_litros_por_minuto / 60; // Volume em litros no intervalo de 1 segundo
        volume_total += volume;                     // Atualiza o volume total

        // A cada minuto, salva o volume em uma variável
        static int segundos = 0;
        segundos++;
        if (segundos >= 60) { // Após 60 segundos
            volume_por_minuto = volume_total;       // Salva o volume total no minuto
            printf("Volume salvo a cada minuto: %.2f litros\n", volume_por_minuto);
            
            volume_por_minuto = 0;                 // Reseta o volume_por_minuto após exibir
            volume_total = 0;                      // Opcional: Reseta volume_total, se necessário
            segundos = 0;                          // Reseta o contador de segundos
        }

        // Exibe os dados periodicamente
        printf("Vazão (L/min): %.2f L/min\n", vazao_litros_por_minuto);
        printf("Volume Total: %.2f litros\n", volume_total);
    }
}
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

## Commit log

2024-10-18 Create Sensor de Volume
2024-10-20 Update README.md
    Add information about the sensor's basic parameters.
2024-11-06 Update README.md
    sensor de volumo
2024-11-06 Update README.md
    Descricao sensor
